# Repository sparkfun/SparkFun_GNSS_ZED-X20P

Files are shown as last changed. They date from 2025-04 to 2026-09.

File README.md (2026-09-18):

SparkFun Allband GNSS RTK Breakout - ZED-X20P (Qwiic)
========================================

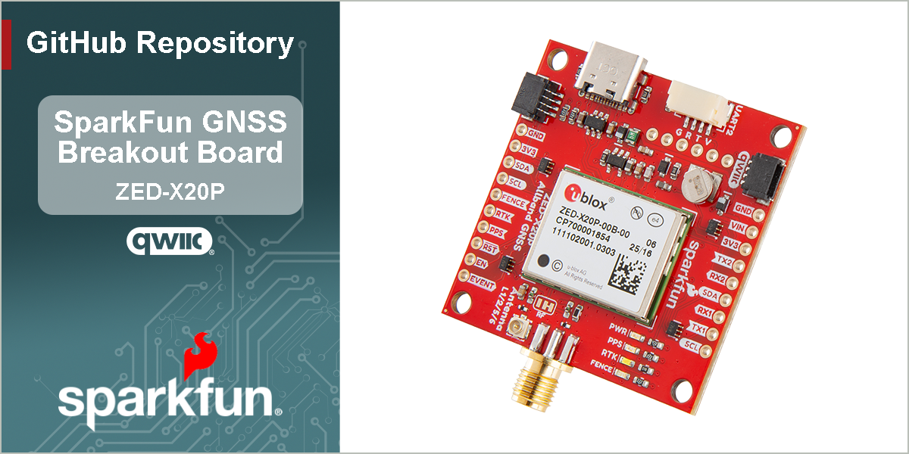
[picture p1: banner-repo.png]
SparkFun Allband GNSS RTK Breakout - ZED-X20P


[*SparkFun Allband GNSS RTK Breakout - ZED-X20P (Qwiic) (GPS-28871)*](https://www.sparkfun.com/sparkfun-allband-gnss-rtk-breakout-zed-x20p-qwiic.html)

The SparkFun All-band GNSS RTK Breakout - ZED-X20P (Qwiic) features the latest GNSS engine from u-blox; the X20, which is a successor to their popular F9 engine. This board's dimensions, pin layout, and connectors are very similar to the [SparkFun GPS-RTK-SMA Breakout - ZED-F9P (Qwiic)](https://www.sparkfun.com/sparkfun-gps-rtk-sma-breakout-zed-f9p-qwiic.html); and in most circumstances, can be used as a drop-in replacement. The board also accommodates users with a diverse choice of interfaces including USB, UART, SPI, and I<sup>2</sup>C.

The ZED-X20P module is an all-band, high precision GNSS receiver that concurrently processes signals from the GPS, Galileo, BeiDou, QZSS, and NavIC constellations across all GNSS frequency bands, including L-band. With positioning algorithms for Real-time Kinematics (RTK), PPP-RTK, and Precise Point Positioning* (PPP) technologies, the module supports standard RTCM corrections for Virtual Reference Stations (VRS) in a Network RTK setup or a local base station setup. Additionally, L-band correction services are natively supported without the need to integrate an external receiver, such as the NEO-D9S.

With its very high update rate, the ZED-X20P module is ideal for control applications, ensuring smooth and reliable operation. The module also protects system integrity with multi-layered defenses, including a Root of Trust, jamming and spoofing detection, cryptographic authentication of navigation messages through Galileo OSNMA, and more. This represents the highest level of integration in a single-chip receiver for the navigation and robotics markets; in unmanned autonomous vehicles (UAVs), guidance systems, and auto-steering applications.

The ZED-X20P module is supported by the u-blox u-center 2 GNSS software for real-time performance analysis, receiver configuration, and data logging. The AssistNow Online, Offline, and Autonomous A-GNSS services can also be used with the module for faster satellite acquisition. Users can also interface with the GNSS module using NMEA 4.11 and UBX binary protocols.

> [!NOTE]
> The USB interface does not fully comply with industry standards and is not suitable for production use. The USB 2.0 FS (full speed, 12 Mbit/s) interface can be used for host communication. Due to the hardware implementation, it may not be possible to certify the USB interface.
>
> `*`: Feature in development

Documentation
-------------

- **[Hookup Guide (mkdocs)](http://docs.sparkfun.com/SparkFun_GNSS_ZED-X20P/)** - A hookup guide for the SparkFun Allband GNSS RTK Breakout - ZED-X20P breakout board hosted by GitHub pages.<br>
   
- [SparkFun u-blox GNSS v3 Arduino Library](https://github.com/sparkfun/SparkFun_u-blox_GNSS_v3) - An Arduino library for the u-blox GNSS modules

Repository Contents
-------------------

- **[/docs](/docs/)** - Online documentation files
  - [/assets](/docs/assets/) - Assets files
    - [/3d_model](/docs/assets/3d_model/) - 3D models for the board
    - [/board_files](/docs/assets/board_files/) - Design files for the board
      - [KiCad Design Files](/docs/assets/board_files/kicad_files.zip) (.zip)
      - [Schematic](/docs/assets/board_files/schematic.pdf) (.pdf)
      - [Dimensions](/docs/assets/board_files/dimensions.pdf) (.pdf)
    - [/component_documentation](/docs/assets/component_documentation/) - Datasheets for hardware components
    - [/img/hookup_guide](/docs/assets/img/hookup_guide/) - Images for hookup guide documentation - Hookup guide images for the board
    - /Hardware - Hardware design files (.brd, .sch)
      - /Production - Production files

Product Variants
----------------

- [GPS-28871](https://www.sparkfun.com/sparkfun-allband-gnss-rtk-breakout-zed-x20p-qwiic.html) - Breakout Board
- Flex Modules
  - [GPS-29362](https://www.sparkfun.com/sparkpnt-gnss-flex-module-zed-x20p.html) - SparkPNT GNSS Flex Module
  - [GPS-28997](https://www.sparkfun.com/sparkpnt-gnss-flex-module-zed-x20p-im19-imu.html) - SparkPNT GNSS Flex Module w/ IMU
- pHAT Kits:
  - [GPS-29887](https://www.sparkfun.com/sparkfun-gnss-flex-phat-zed-x20p.html) - SparkFun GNSS Flex pHAT
  - [GPS-29888](https://www.sparkfun.com/sparkfun-gnss-flex-phat-zed-x20p-im19-imu.html) - SparkFun GNSS Flex pHAT w/ IMU

Version History
---------------

- [v10](https://github.com/sparkfun/SparkFun_GNSS_ZED-X20P/releases/tag/v10) - Initial Release

License Information
-------------------

This product is ***open source***!

Please review the [`LICENSE.md`](./LICENSE.md) file for license information.

If you have any questions or concerns about licensing, please contact technical support on our [SparkFun forums](https://forum.sparkfun.com/viewforum.php?f=152).

Distributed as-is; no warranty is given.

- Your friends at SparkFun.

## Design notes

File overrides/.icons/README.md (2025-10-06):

.icons directory
====================
This folder should contain branding logos for the product documentation

## General Images
- `sfe.svg` - SparkFun flame logo
- `kicad-primary.svg` - Full KiCad logo

## Directory
- `logo` - Other available logos

## SVG Optimizer
- [Remove meta data from svg](https://jakearchibald.github.io/svgomg/)

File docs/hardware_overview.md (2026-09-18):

## :material-folder-cog: Design Files

<!-- Import the component -->
<script type="module" src="https://ajax.googleapis.com/ajax/libs/model-viewer/3.5.0/model-viewer.min.js"></script>

<div class="grid cards desc" markdown>

-   :kicad-primary:{ .enlarge-logo } Design Files

	---

	- :fontawesome-solid-file-pdf: [Schematic](./assets/board_files/schematic.pdf)
	- :material-folder-zip: [KiCad Files](./assets/board_files/kicad_files.zip)
	- :material-rotate-3d: [STEP File](./assets/3d_model/cad_model.step)
	- :fontawesome-solid-file-pdf: [Board Dimensions](./assets/board_files/dimensions.pdf):
		- 1.70" x 1.70" (43.2mm x 43.2mm)

-   <!-- Boxes in tabs -->

	=== "3D Model"
		<article style="text-align: center;" markdown>
		<model-viewer src="../assets/3d_model/web_model.glb" camera-controls poster="../assets/3d_model/poster.png" tone-mapping="neutral" shadow-intensity="2" shadow-softness="0.2" camera-orbit="0deg 75deg 0.103m" field-of-view="25.11deg" style="width: 100%; height: 450px;">
		</model-viewer>

		[Download the `*.step` File](./assets/3d_model/cad_model.step "Click download"){ .md-button .md-button--primary width="250px" }

		</article>

		???+ tip "Manipulate 3D Model"
			<article style="text-align: center;" markdown>

			| Controls       | Mouse                    | Touchscreen    |
			| :------------- | :----------------------: | :------------: |
			| Zoom           | Scroll Wheel             | 2-Finger Pinch |
			| Rotate         | ++"Left-Click"++ & Drag  | 1-Finger Drag  |
			| Move/Translate | ++"Right-Click"++ & Drag | 2-Finger Drag  |

			</article>

	=== "Dimensions"
		<article style="text-align: center;" markdown>
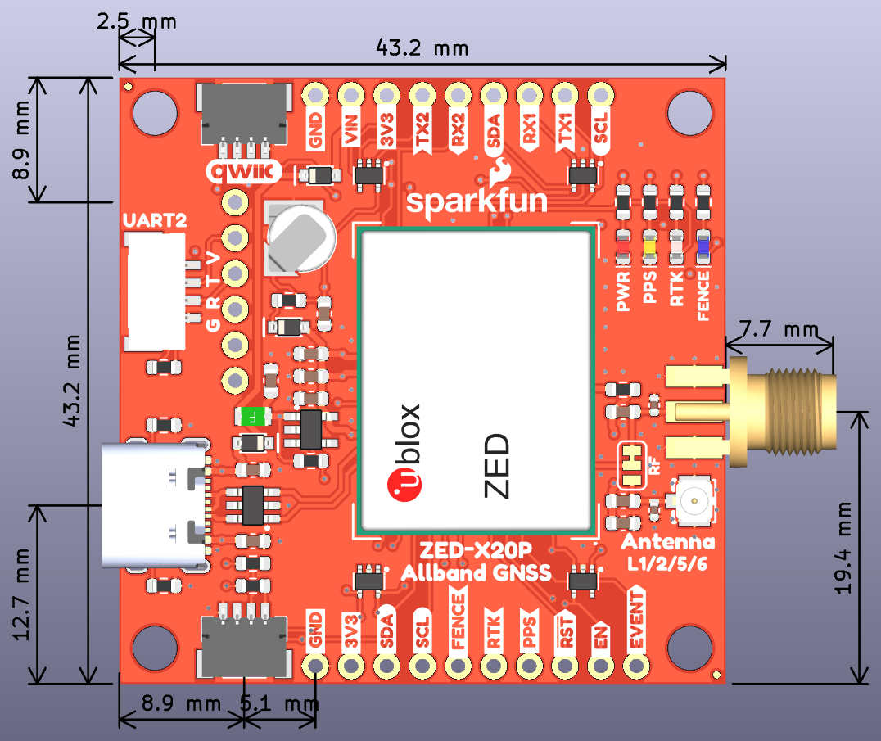
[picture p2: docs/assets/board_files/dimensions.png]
Board Dimensions
		
		<figcaption markdown>Dimensions of the ZED-X20P GNSS breakout board.</figcaption>
		</article>

		???+ tip "Need more measurements?"
			For more information about the board's dimensions, users can download the [KiCad files](./assets/board_files/kicad_files.zip) for this board. These files can be opened in KiCad and additional measurements can be made with the measuring tool.

			!!! info ":octicons-download-16:{ .heart } KiCad - Free Download!"
				KiCad is free, open-source [CAD]("computer-aided design") program for electronics. Click on the button below to download their software. *(\*Users can find out more information about KiCad from their [website](https://www.kicad.org/).)*

				<article style="text-align: center;" markdown>
				[Download :kicad-primary:{ .enlarge-logo }](https://www.kicad.org/download/ "Go to downloads page"){ .md-button .md-button--primary width="250px" }
				</article>

			???+ info ":straight_ruler: Measuring Tool"
				This video demonstrates how to utilize the dimensions tool in KiCad, to include additional measurements:

				<article class="video-500px" style="text-align: center; margin: auto;" markdown>
				<iframe src="https://www.youtube.com/embed/-eXuD8pkCYw" title="KiCad Dimension Tool" frameborder="0" allow="accelerometer; autoplay; clipboard-write; encrypted-media; gyroscope; picture-in-picture" allowfullscreen></iframe>
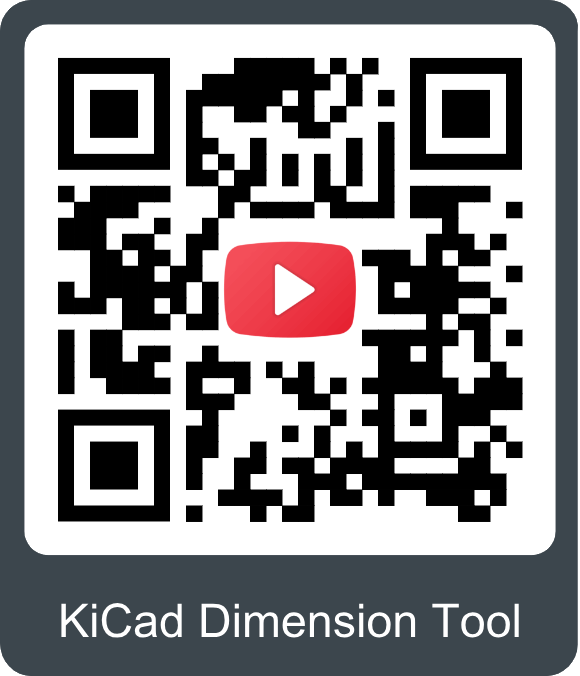
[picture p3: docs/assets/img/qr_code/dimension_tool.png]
QR code to play video
				
				</article>

</div>

## Board Layout
The SparkFun Allband GNSS RTK Breakout - ZED-X20P (Qwiic) features the following:

<div class="grid" markdown>

<div markdown>

<figure markdown>
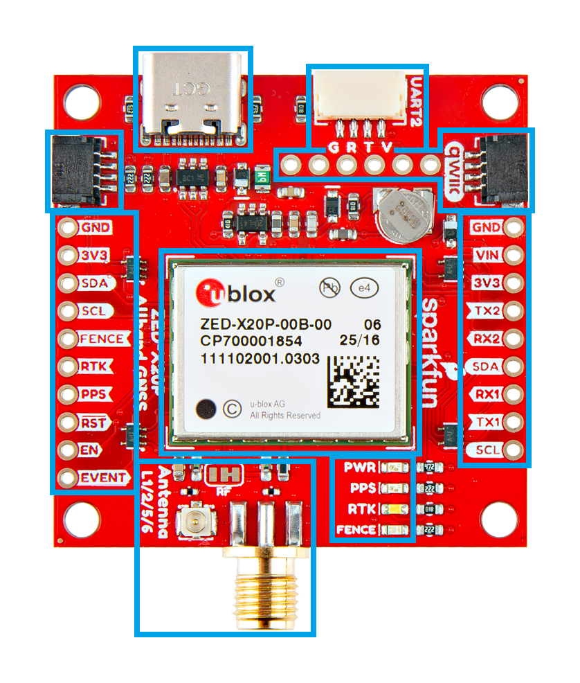
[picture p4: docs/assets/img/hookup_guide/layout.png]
Layout

<figcaption markdown>Layout of the major components on the breakout board.</figcaption>
</figure>

</div>

<div markdown>

1. **USB-C Connector**
:   The primary inteface for powering and interacting with the board
1. **ZED-X20P GNSS Module**
:   The u-blox ZED-X20P GNSS module
1. **Header Pins**
:   Exposes pins to power the board and breaks out the interfaces of the ZED-X20P GNSS module
1. **BlueSMiRF Header Pins**
:   Exposes the `UART2` interface of the ZED-X20P GNSS module
1. **JST Connector**
:   Exposes the `UART2` interface of the ZED-X20P GNSS module
1. **Qwiic Connectors**
:   Exposes the I^2^C interface of the ZED-X20P GNSS module
1. **Status LEDs**
:   LED status indicators for the ZED-X20P GNSS module
1. **`Antenna L1/2/5/6` RF Connectors**
:   SMA and U.FL *(optional)* connectors for an external GNSS antenna

</div>

</div>

## USB-C Connector
A USB connector is provided to power the board and interface with the ZED-X20P GNSS receiver. For most users, it will be the primary method for communicating with the ZED-X20P module.

<figure markdown>
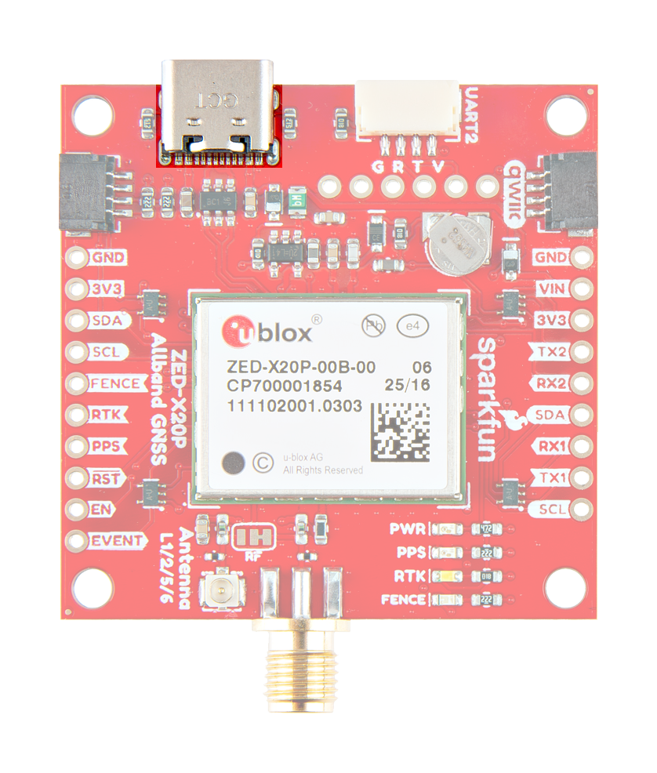
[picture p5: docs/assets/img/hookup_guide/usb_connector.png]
USB-C Connector

<figcaption markdown>USB-C connector on the ZED-X20P GNSS breakout board.</figcaption>
</figure>

## Power
The simplest method to power the board is through the USB-C connector. However, the ZED-X20P GNSS breakout board only requires **3.3V** to power most of its components(1), which can be supplied though JST connector, Qwiic connector, or [PTH](https://en.wikipedia.org/wiki/Through-hole_technology "Plated Through Holes") pins.
{ .annotate }

1. 5V is only required to utilize the USB interface; and when enabled, it can also power the JST connector.

<figure markdown>
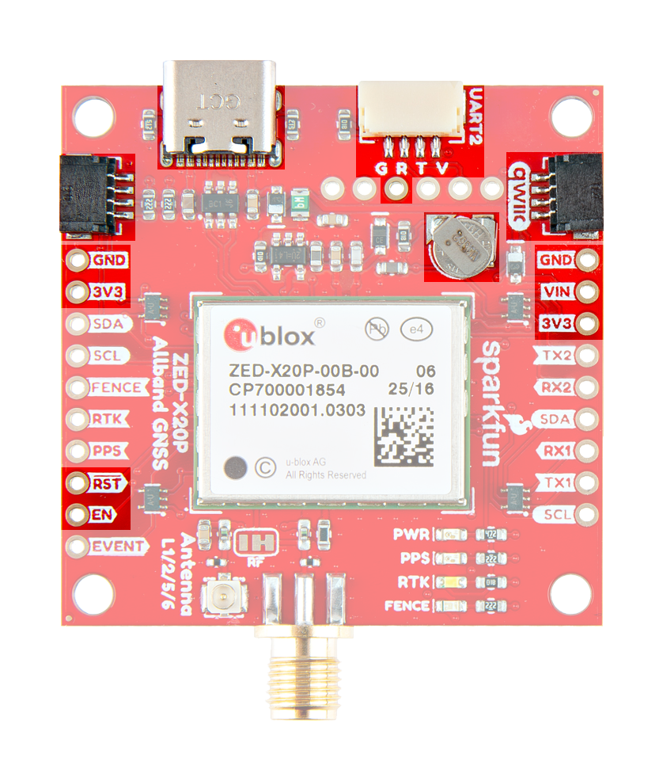
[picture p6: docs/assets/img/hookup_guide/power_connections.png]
Power connections

<figcaption markdown>ZED-X20P GNSS breakout board's power connections.</figcaption>
</figure>

Below, is a general summary of the power circuitry on the board; most are broken out as [PTH](https://en.wikipedia.org/wiki/Through-hole_technology "Plated Through Holes") pins:

<div class="annotate" markdown>

- **`VIN`** - The voltage from the USB-C connector, usually **5V**.
	- Input Voltage Range: 1.2 - 5.5V (1)
	- Power source for the entire board
		- Powers the 3.3V voltage regulator (RT9080), which can source up to 600mA
		- When enabled, it can also power the [BlueSMiRF header](#bluesmirf-header)
- **`3V3`** - Provides a regulated 3.3V from the [RT9080](./assets/component_documentation/RT9080.pdf), using the power supplied from the `VIN` pin or USB-C connector.
	- Used to power the ZED-X20P module, LEDs, [Qwiic connectors](#qwiic), [BlueSMiRF header](#bluesmirf-header), and backup battery
	- Controlled by the `EN` pin, which is enabled by default
- **`EN`** - Enables the voltage output from the [RT9080](./assets/component_documentation/RT9080.pdf), 3.3V voltage regulator
	- Enabled by default *(active `HIGH`)*
- **`RST`** - Used to reset the ZED-X20P GNSS module
	- Connected to the [`RESET_N` pin](#pio-pins) of the ZED-X20P module, an input-only pin with an internal pull-up resistor (2)
	- Driving the pin `LOW` for at least 100ms triggers a cold-start reset, clearing the `BBR` content *(receiver configuration, real-time clock (RTC), and GNSS orbit data)*
- **`GND`** - The common ground or the 0V reference for the voltage supplies.
- **Backup Battery** - Provides backup power to the ZED-X20P GNSS module to maintain ephemeris data for warm starts

</div>

1. While the [RT9080](./assets/component_documentation/RT9080.pdf) LDO regulator has an input voltage range of 1.2 - 5.5V, a minimum supply voltage of **3.5V** is recommended for a 3.3V output.

1. No capacitors should be placed between `RESET_N` to GND, otherwise it could trigger a reset on every startup.

!!! tip "JST Connector"
	The `VSEL` pin of the [BlueSMiRF header](#bluesmirf-header) is designed to operate as a voltage output. However, an input voltage can be supplied through the pin, but users should be mindful of any voltage contention issues.

	Additionally, the jumper for the `VSEL` pin can be modified to change to output voltage level.

!!! info
	For more details, users can reference the [schematic](./assets/board_files/schematic.pdf) and the datasheets of the individual components on the board.

<!-- Not detailed in the datasheet or integration manual, information pulled from another u-blox GNSS module
### Power Modes
The ZED-X20P GNSS module supports three different operation modes:

- **Continuous Mode**

:   In this mode, the module uses dedicated signal processing engines optimized for signal acquisition and tracking.

	- The acquisition engine actively searches and acquires signals, during cold starts or when insufficient signals are available during navigation.
	- The tracking engine continuously tracks signals, downloads all the almanac data, and acquires new signals as they become available during navigation.
	
	The tracking engine consumes less power than the acquisition engine. Therefore, the module's current consumption is lower when a valid position is obtained quickly after startup, the entire almanac has been downloaded, and the ephemeris for available satellites are valid.

- **Backup Modes**

:   The ZED-X20P module supports two backup modes. The backup modes are inactive states with reduced power consumption, where the receiver maintains time, information, and navigation data to speed up signal acquisitions upon restart.

	- **Hardware backup mode**

	:   The hardware backup mode requires `V_BCKP` power to be supplied. It allows the module to enter a backup state and maintain the backup domain (`BBR` and `RTC`), after the main power has been switched off.

	- **Software standby mode**

	:   Software standby mode is entered using the `UBX-RXM-PMREQ` message. This mode will clear the RAM memory; to maintain the receiver configuration, it should be stored on `BBR` or flash layers. The software standby mode can be set for a specific duration, or until the receiver is woken up by a signal from the UART `RX` and/or `EXTINT` pins, as defined in `UBX-RXM-PMREQ` message. A system reset with the `RESET_N` signal also terminates the software standby mode, clears the `BBR` content and restarts the receiver.

- **Safe Boot Mode**
-->

### Power Consumption
The power consumption of the ZED-X20P module depends on the GNSS signals enabled and if the module is acquiring or tacking those signals. The table below, lists the average current consumption with a supply voltage of 3.3V.

<div class="grid cards" markdown>

<article style="text-align: center;" markdown>

| GNSS Signals | Acquisition | Tracking |
| :--- | :---: | :---: |
| GPS+GAL+BDS  | 68mA | 64mA |
| GPS | 55mA | 55mA |

</article>

<div markdown>

!!! tip
	During acquisition, the current consumption may reach up to 85mA; make sure the primary power source can sustain this.

<!--
!!! info "Backup Modes"
	The current consumption for the backup modes:

	- Hardware backup Mode: 31µA
	- Software standby Mode: 49µA
-->

!!! info
	For more information, please refer to the [ZED-X20P Datasheet](./assets/component_documentation/ZED-X20P-00B_DataSheet_UBXDOC-963802114-12690.pdf).

</div>

</div>

## ZED-X20P GNSS Receiver
The centerpiece of this GNSS breakout board is the [ZED-X20P module](./assets/component_documentation/ZED-X20P-00B_DataSheet_UBXDOC-963802114-12690.pdf) from [u-blox](https://www.u-blox.com/en); it features their latest X20 GNSS engine, a successor to their popular F9 engine. The ZED-X20P module is an all-band, high precision GNSS receiver that concurrently processes signals from the GPS, Galileo, BeiDou, QZSS, and NavIC constellations across all GNSS frequency bands, including L-band. With positioning algorithms for Real-time Kinematics (RTK), PPP-RTK, and Precise Point Positioning* (PPP) technologies, the module supports standard RTCM corrections for Virtual Reference Stations (VRS) in a Network RTK setup or a local base station setup. Additionally, L-band correction services are natively supported without the need to integrate an external receiver, such as the NEO-D9S.

With its very high update rate, the ZED-X20P module is ideal for control applications, ensuring smooth and reliable operation. The module also protects system integrity with multi-layered defenses, including a Root of Trust, jamming and spoofing detection, cryptographic authentication of navigation messages through Galileo OSNMA, and more. The module also accommodates users with a diverse choice of interfaces including USB, UART, SPI, and I^2^C.

<div class="grid cards" markdown>

<div markdown>

!!! note
	`*`: Feature in development

<figure markdown>
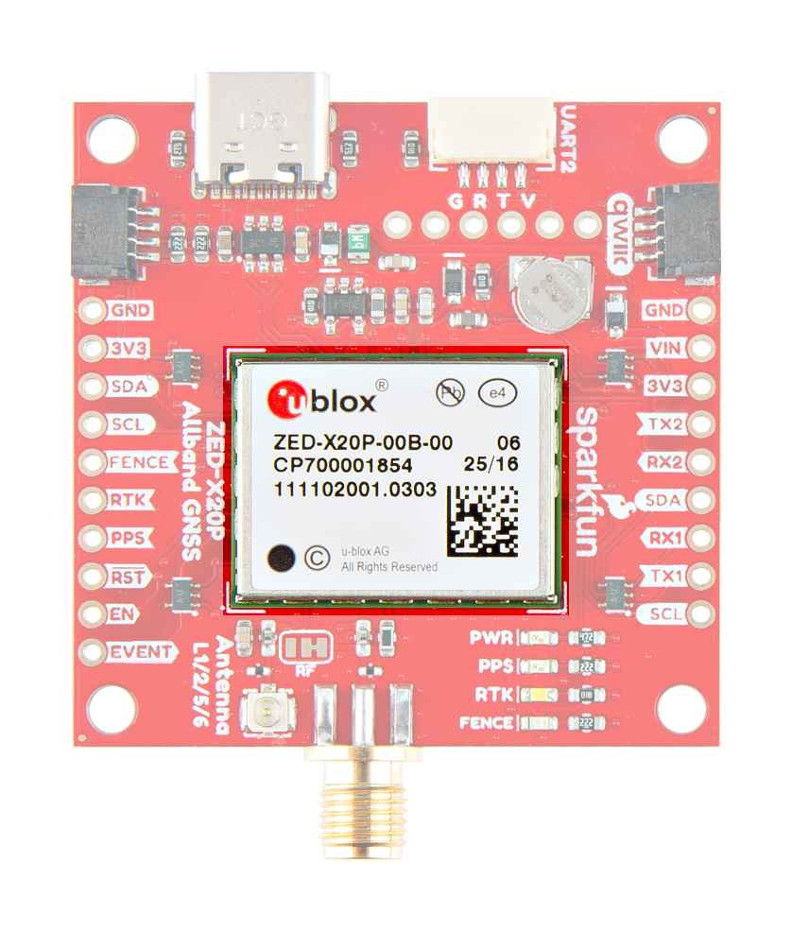
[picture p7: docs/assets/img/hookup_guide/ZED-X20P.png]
ZED-X20P module

<figcaption markdown>The ZED-X20P module on the breakout board.</figcaption>
</figure>

</div>

<div markdown>

<article class="video-500px" style="margin: auto;" markdown>
<iframe src="https://www.youtube.com/embed/dRFR38xS2b4" title="u-blox launches the ZED-X20P. Our first all-band, global GNSS module." frameborder="0" allow="accelerometer; autoplay; clipboard-write; encrypted-media; gyroscope; picture-in-picture" allowfullscreen></iframe>
QR code to play video
</article>

<figure markdown>
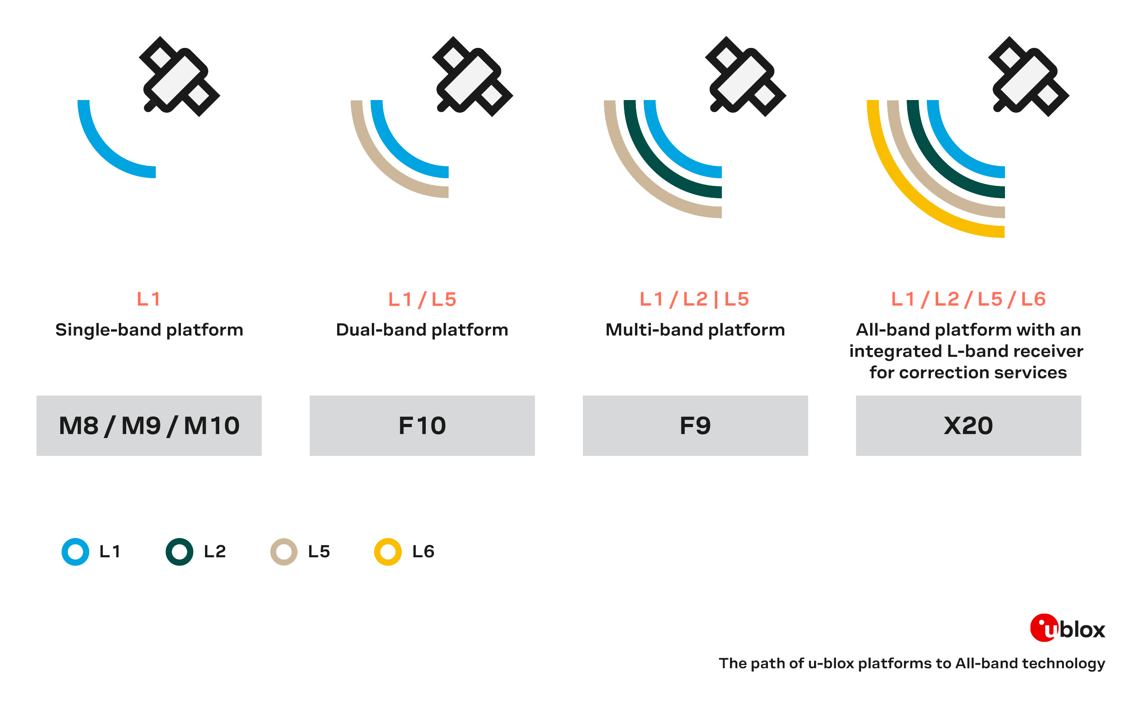
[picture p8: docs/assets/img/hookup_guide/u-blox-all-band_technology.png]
ublox engine (https://content.u-blox.com/sites/default/files/2024-09/X20-u-blox-the-path-of-u-blox-platforms-to-all-band-technologyx20-u-blox-the-path-of-u-blox-platforms-to-all-b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 "Click to enlarge")

<figcaption markdown>The frequency bands supported by the various u-blox GNSS engines.</figcaption>
</figure>

</div>

</div>

<div class="grid" markdown>

<div markdown>

**Features:**

- Supply voltage: 2.7V to 3.6V
- GNSS Constellations:
	- GPS (USA)
	- Galileo (EU)
	- BDS (China)
	- QZSS (Japan)
	- NavIC (India)
- SBAS Systems:
	- WASS (USA)
	- EGNOS (EU)
	- BDSBAS (China)
	- MSAS (Japan)
	- GAGAN (India)
- Sensitivity
	- Tracking and Nav.: -167dBm
	- Reacquisition: -160dBm
	- Cold start: -148dBm
	- Hot start: -158dBm
- Accuracy
	- Dynamic
		- Velocity: 0.03m/s
		- Heading: 0.3&deg;
		- Time Pulse: 60ns
	- Static/Position *(GPS+GAL+BDS)*
		- Horizontal position accuracy (CEP)
			- PVT: 1.2m
			- SBAS: 0.6m
			- RTK: 0.006m + 1ppm
			- PPP-RTK: <0.06m
			- PPP: <0.10m

</div>

<div markdown>

<br>

- Operational limits
	- Dynamics: <4g
	- Altitude: 80,000m
	- Velocity: 300m/s
	- Update Rate: Up to 25Hz
- Time to Fix
	- Cold Start: 25s
	- Aided Start: 2s
	- Hot Start: 2s
- Convergence time:
	- RTK: <7s
	- PPP-RTK: <40s
	- PPP: <120s
- Features
	- Programmable flash memory
	- Carrier phase output
	- Jamming detection
	- Galileo OSNMA
	- Secure boot
- Interfaces:
	- USB
	- UART x2
	- SPI
	- I^2^C
	- Digital I/O
		- `TIMEPULSE` configurable: 0.25 - 10MHz
		- `EXTINT` input for Wakeup
- Protocols: NMEA 4.11, UBX binary, RTCM v. 3.4, SPARTN v. 2.0.2
- Services:
	- AssistNow
	- PointPerfect
- Operating temperature: -40°C to 85°C
- Dimensions: 17.0mm x 22.0mm x 2.4mm

</div>

</div>

### Frequency Bands
The ZED-X20P module is an all-band, high precision GNSS receiver that concurrently processes signals from the GPS, Galileo, BeiDou, QZSS, and NavIC constellations across all GNSS frequency bands, including L-band. Below, are the frequency bands provided by all the global navigation satellite systems and the ones supported by the ZED-X20P module.

<div class="grid" markdown>

<div markdown>

<figure markdown>
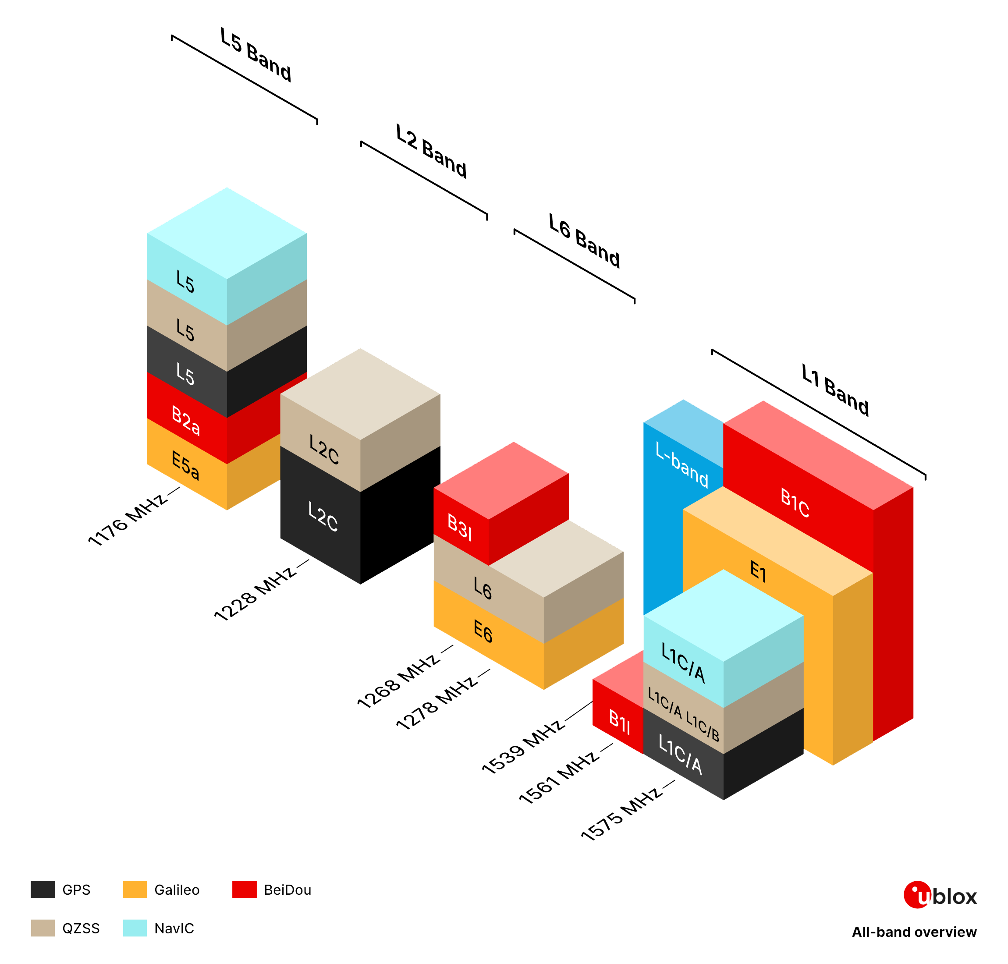
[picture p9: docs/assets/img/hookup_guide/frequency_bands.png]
Supported frequency bands (https://content.u-blox.com/sites/default/files/2025-03/all-band-overview-design.png "Click to enlarge")

<figcaption markdown>The frequency bands supported by the ZED-X20P GNSS receiver.</figcaption>
</figure>

</div>

<div markdown>

<article style="text-align: center;" markdown>

| Constellation | Frequency Bands |
| :---: | :--- |
| GPS | L1C/A, L2C, L5 |
| QZSS | L1C/A, L1C/B*, L2C, L5, L6 |
| GAL | E1B/C, E5a, E6 |
| BDS | B1I, B1C, B2a, B3I |
| NavIC | L1*, L5 |
| SBAS | L1C/A |

*The supported frequency bands, organized by constellation.*
</article>

!!! note
	`*`: Feature in development

</div>

</div>

<figure markdown>
GNSS frequency bands (https://www.tallysman.com/app/uploads/2021/07/Tallysman-GNSS-Frequencies-v8.0_Chart-1-1024x425.png "Click to enlarge")
<figcaption markdown>Frequency bands of the global navigation satellite systems. (Source: [Tallysman](https://www.tallysman.com/gnss-constellations-radio-frequencies-and-signals/))</figcaption>
</figure>

!!! note "Configuration Settings"
	Each GNSS constellations and their signal bands can be enabled or disabled independently, using keys from the `CFG-SIGNAL-*` configuration group; except for the QZSS and SBAS constellation. A GNSS constellation is considered to be enabled when the constellation enable key is set and at least one of the constellation's band keys is enabled. However, the ZED-X20P only supports certain combinations of constellations and bands. For all GNSS constellations, the `L1` band is mandatory even in combination with another frequency band. Any unsupported combinations will be rejected with a `UBX-ACK-NAK` and the warning: `inv sig cfg` will be sent via UBX-INF and NMEA-TXT messages *(if enabled)*.

	??? info "Supported Combinations"

		<article style="text-align: center;" markdown>

		| Constellation key<br>`CFG-SIGNAL-GAL_ENA` | Band key<br>`CFG-SIGNAL-GAL_E1_ENA` | Band key<br>`CFG-SIGNAL-GAL_E5A_ENA` | Band key<br>`CFG-SIGNAL-GAL_E6_ENA` | Constellation enabled? |
		| :---------- | :---------- | :---------- | :---------- | :-: |
		| true (`1`)  | true (`1`)  | true (`1`)  | true (`1`)  | yes |
		| true (`1`)  | true (`1`)  | true (`1`)  | false (`0`) | yes |
		| true (`1`)  | true (`1`)  | false (`0`) | true (`1`)  | yes |
		| true (`1`)  | true (`1`)  | false (`0`) | false (`0`) | yes |
		| true (`1`)  | false (`0`) | true (`1`)  | true (`1`)  | no  |
		| true (`1`)  | false (`0`) | false (`0`) | true (`1`)  | no  |
		| true (`1`)  | false (`0`) | true (`1`)  | false (`0`) | no  |
		| true (`1`)  | false (`0`) | false (`0`) | false (`0`) | no  |
		| false (`0`) | true (`1`)  | true (`1`)  | true (`1`)  | no  |
		| false (`0`) | true (`1`)  | true (`1`)  | false (`0`) | no  |
		| false (`0`) | true (`1`)  | false (`0`) | true (`1`)  | no  |
		| false (`0`) | false (`0`) | true (`1`)  | true (`1`)  | no  |
		| false (`0`) | false (`0`) | false (`0`) | true (`1`)  | no  |
		| false (`0`) | false (`0`) | true (`1`)  | false (`0`) | no  |
		| false (`0`) | true (`1`)  | false (`0`) | false (`0`) | no  |
		| false (`0`) | false (`0`) | false (`0`) | false (`0`) | no  |

		</article>

??? info "What are Frequency Bands?"
	A [frequency band](https://en.wikipedia.org/wiki/Frequency_band) is a section of the [electromagnetic spectrum](https://en.wikipedia.org/wiki/Electromagnetic_spectrum), usually denoted by the range of its upper and lower limits. In the [radio spectrum](https://en.wikipedia.org/wiki/Radio_spectrum), these frequency bands are usually regulated by region, often through a government entity. This regulation prevents the interference of RF communication; and often includes major penalties for any interference with critical infrastructure systems and emergency services.

	<figure markdown>
	GNSS frequency bands (https://gssc.esa.int/navipedia/images/c/cf/GNSS_All_Signals.png "Click to enlarge")
	<figcaption markdown>Frequency bands of the global navigation satellite systems. (Source: [ESA](https://gssc.esa.int/navipedia/index.php?title=File:GNSS_All_Signals.png "European Space Agency"))</figcaption>
	</figure>

	However, if the various GNSS constellations share similar frequency bands, then how do they avoid interfering with one another? Without going too far into detail, the image above illustrates the frequency bands of each system with a few characteristics specific to their signals. Wit these characteristics in mind, along with other factors, the chart can help users to visualize how multiple GNSS constellations might co-exist with each other.

	For more information, users may find these articles of interest:

	- [GNSS signal](https://gssc.esa.int/navipedia/index.php/GNSS_signal)
	- [GPS Signal Plan](https://gssc.esa.int/navipedia/index.php?title=GPS_Signal_Plan)
	- [GLONASS Signal Plan](https://gssc.esa.int/navipedia/index.php?title=GLONASS_Signal_Plan)
	- [GALILEO Signal Plan](https://gssc.esa.int/navipedia/index.php?title=GALILEO_Signal_Plan)

## Peripherals and I/O Pins
The ZED-X20P module has twenty-one I/O pins, of which eight are programmable. Most of these are broken out as [PTH](https://en.wikipedia.org/wiki/Through-hole_technology "Plated Through Holes") pins on the ZED-X20P GNSS breakout board; whereas, others are broken out to their specific interface *(i.e. USB connector, jumper, U.FL connector, etc.)*. Additionally, some of the I/O connections are broken out with multiple components or interfaces.

<div class="grid cards" markdown>

<div markdown>

<figure markdown>
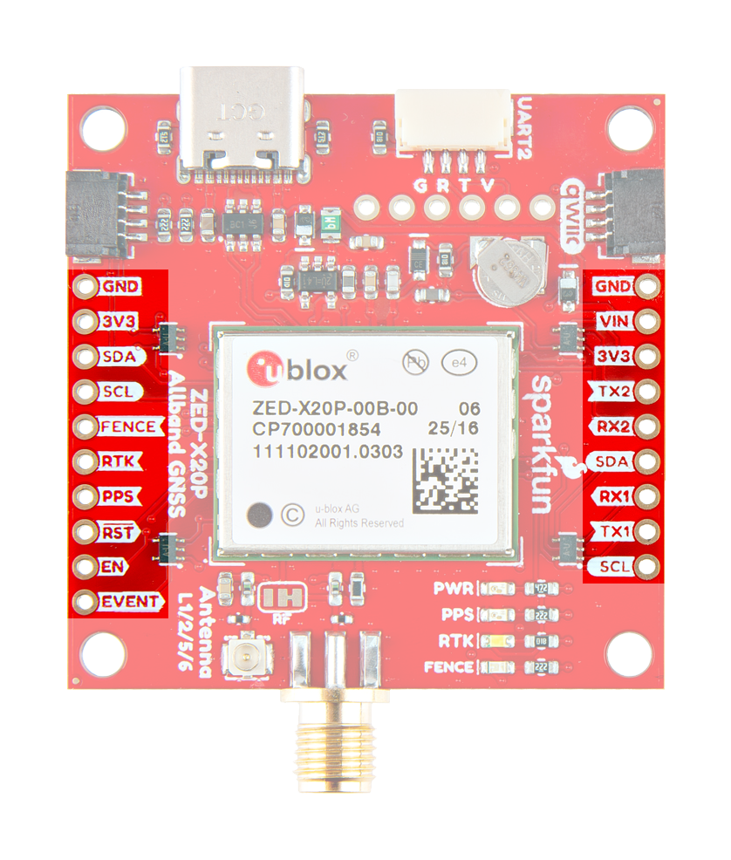
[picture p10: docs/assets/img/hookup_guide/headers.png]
Header pins

<figcaption markdown>The header pins on the ZED-X20P GNSS breakout board.</figcaption>
</figure>

</div>

<div markdown>

<article class="annotate" markdown>
**Interfaces:**

- USB
- UART x2
- SPI
- I^2^C
	- Address *(7-bit)*: **0x42** *(`1000010`)*
- ~~1x Antenna Detect~~ (1)
- ~~1x Antenna Short~~ (2)
- ~~1x Antenna Off~~ (3)
- 1x External interrupt
- 1x PPS output signal
- 1x TX Ready
- 1x RTK Stat
- 1x Geo Stat
- 1x D_Sel pin
- 1x Safe boot pin
- 1x Reset pin

</article>

1. Not available on the ZED-X20P GNSS breakout board.
1. Not available on the ZED-X20P GNSS breakout board.
1. Not available on the ZED-X20P GNSS breakout board.

</div>

</div>

<!--
!!! info "Pin States"
	This table defines the state of the PIO and `RESET_N` pins in different operational modes. The functions of the PIOs are as defined in the default configuration.

	<article style="text-align: center;" markdown>

	| Pin no. | Default function | Continuous mode | Software standby mode | Safe boot mode |
	| :-----: | :--------------- | :-------------: | :-------------------: | :------------: |
	| 47 | `D_SEL`=open<br>`D_SEL`=`GND` | Input pull-up<br>High-Z | Input pull-up<br>Input pull-down | Input pull-up<br>High-Z |
	| 43 | `RXD`<br>`SPI_SDO` | Input pull-up<br>High-Z | Input pull-up | Input pull-up |
	| 42 | `TXD`<br>`SPI_SDI` | Output | Input pull-up | Output |
	| 44 | `SDA`<br>`SPI_CS_N` | Input pull-up / Output<br>High-Z | Input pull-up<br>High-Z | Input pull-up / Output<br>High-Z |
	| 45 | `SCL`<br>`SPI_SLK` | Input pull-up<br>High-Z | Input pull-up<br>High-Z | Input pull-up<br>High-Z |
	| 53 | `TIMEPULSE` | Output | Input pull-up | Output low |
	| 50 | `SAFEBOOT_N` | Input pull-up | Input pull-up | Input pull-up |
	| 51 | `EXTINT` | Input pull-up | Input pull-up | Input pull-up |
	| 26 | `RXD2` | Input pull-up | Input pull-up | Input pull-up |
	| 27 | `TXD2` | Output | Input pull-up | Output |
	| 49 | `RESET_N` | Input pull-up | Input pull-up | Input pull-up |

	</article>

	!!! note
		In reset mode (`RESET_N` = `LOW`), all PIOs are configured as input pull-up.

		In hardware backup mode (VCC = 0V), PIOs must not be driven.
-->

=== "UART Interface"
	The ZED-X20P has two UART interfaces that can be accessed either through the [PTH](https://en.wikipedia.org/wiki/Through-hole_technology "Plated Through Holes") pins. The `UART2` interface can also be accessed through the [BlueSMiRF header](#bluesmirf-header) and the [JST connector](#jst-connector).

	<div class="grid cards desc" markdown>

	<div markdown>

	<figure markdown>
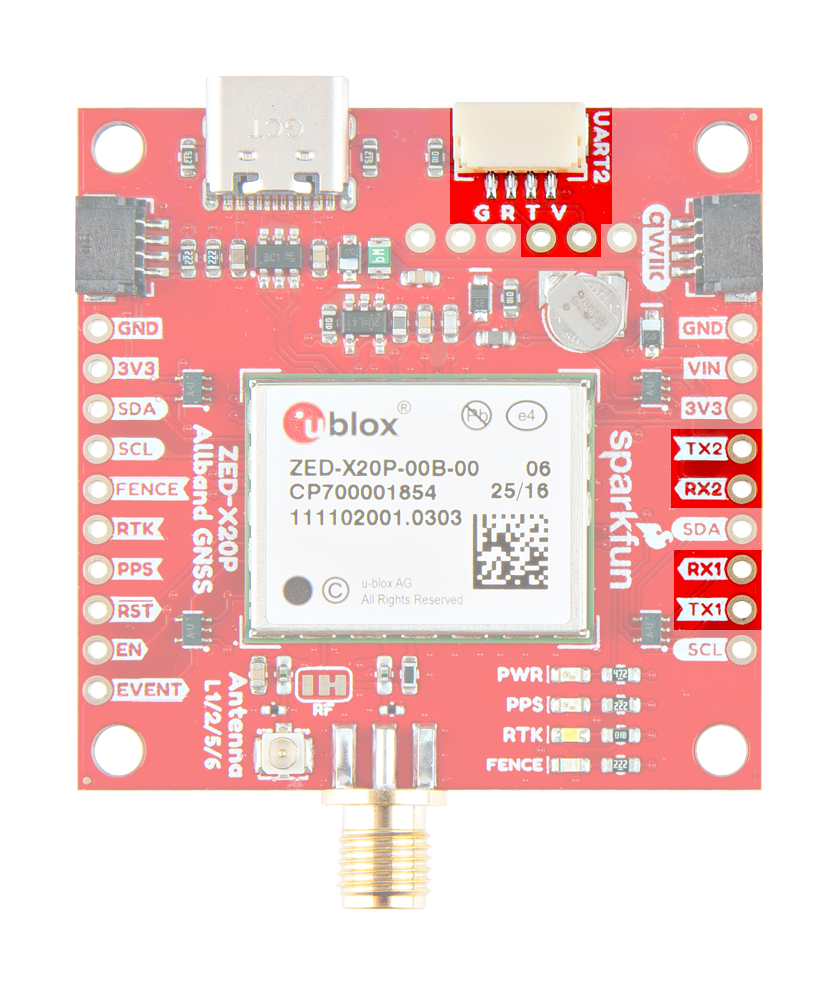
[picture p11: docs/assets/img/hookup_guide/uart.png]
UART connections
	
	<figcaption markdown>The UART interfaces on the ZED-X20P GNSS breakout board.</figcaption>
	</figure>

	!!! tip
		The UART `RX` interface will be disabled when more than 100 frame errors are detected during a one-second period. This can happen if the wrong baud rate is used or the UART `RX` pin is grounded. An error message appears when the UART `RX` interface is reenabled at the end of the one-second period.

	</div>

	<div markdown>

	!!! info "Supported Protocols"
		The UART interface supports the following protocols:

		- Input messages: NMEA (GGA, GLL, GSA, GSV, RMC, VTG, and TXT), RTCM, SPARTN, and UBX
		- Output messages: NMEA, RTCM, and UBX

	!!! info "Configuration Settings"
		The UART interfaces can be configured with the `CFG-UART*` messages, but will initially have the following settings:

		<div class="grid" markdown>

		<div markdown>

		- Baudrate: 4800 to 8000000bps *(Default: 38400bps)*
		- Data Bits: 8
		- Parity: No
		- Stop Bits: 1
		- Flow Control: None

		</div>

		<div markdown>

		- `UART1` Output
			- NMEA protocol with the GGA, GLL, GSA, GSV, RMC, VTG, and TXT output messages are enabled by default.
			- UBX and RTCM 3.4 protocols are enabled by default, but no output messages are enabled by default.
		- `UART1` Input
			- UBX, NMEA, and RTCM 3.4 input protocols are enabled by default.
		- `UART2` Output
			- RTCM 3.4 protocol is enabled by default, but no output messages are enabled by default.
			- NMEA protocol is disabled by default.
		- `UART2` Input
			- RTCM 3.4 and SPARTN protocols are enabled by default.
			- NMEA protocol is disabled by default.

		</div>

		</div>

	</div>

	</div>

	!!! warning "HPG v2.00 Firmware"
		Previously, with firmware HPG v2.00, firmware updates could only be performed with the `UART1` interface.

=== "I^2^C"
	The ZED-X20P has a single I^2^C interface that can be accessed either through the [PTH](https://en.wikipedia.org/wiki/Through-hole_technology "Plated Through Holes") pins or the [Qwiic connector](#qwiic).

	<figure markdown>
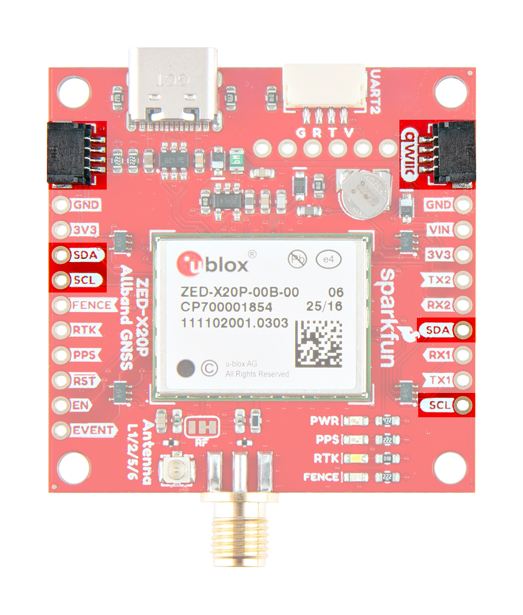
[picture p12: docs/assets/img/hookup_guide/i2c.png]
I2C connections
	
	<figcaption markdown>The I^2^C connections on the ZED-X20P GNSS breakout board.</figcaption>
	</figure>

	!!! info
		For users interested in the specific details about the read and write access for th I^2^C bus, please refer to the [ZED-X20P integration manual](https://www.u-blox.com/sites/default/files/documents/ZED-X20P_IntegrationManual_UBXDOC-963802114-12901.pdf)

	??? tip "What is Qwiic?"

		<div class="grid" markdown>

		<div markdown>

		<!-- Qwiic Banner -->
		<article style="text-align: center;" markdown>
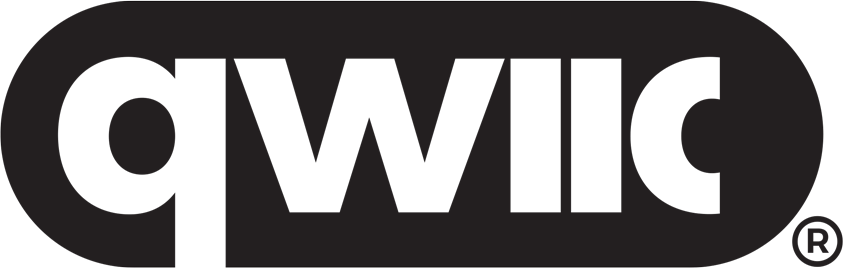
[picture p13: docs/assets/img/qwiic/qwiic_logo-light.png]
Qwiic Logo - light theme (https://www.sparkfun.com/qwiic)
		
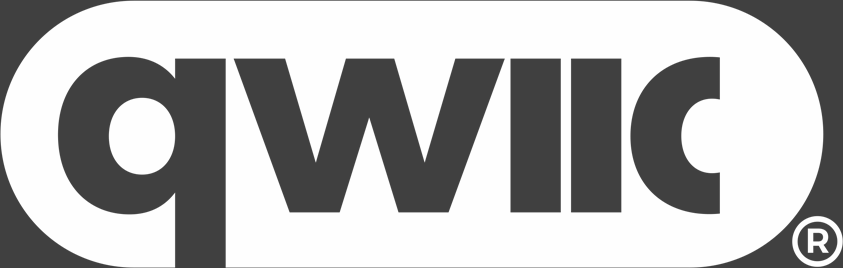
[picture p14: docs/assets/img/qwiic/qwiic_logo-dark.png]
Qwiic Logo - dark theme (https://www.sparkfun.com/qwiic)
		
		</article>

		---

		The [Qwiic connect system](https://www.sparkfun.com/qwiic) is a solderless, polarized connection system that allows users to seamlessly daisy chain I^2^C boards together. Play the video, to learn more about the Qwiic connect system or click on the banner above to learn more about [Qwiic products](https://www.sparkfun.com/qwiic).

		</div>

		<div style="max-height=400px;" markdown>

		<article class="video-500px" style="text-align: center; margin: auto;" markdown>
		<iframe src="https://www.youtube.com/embed/x0RDEHqFIF8" title="SparkFun's Qwiic Connect System" frameborder="0" allow="accelerometer; encrypted-media; gyroscope; picture-in-picture" allowfullscreen></iframe>
		QR code to instructional video
		</article>

		</div>

		</div>

		!!! info "Features of the Qwiic System"

			=== "No Soldering"

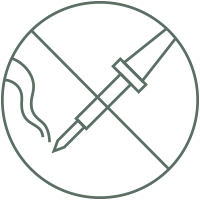
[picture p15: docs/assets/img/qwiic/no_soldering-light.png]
no soldering - light theme
				
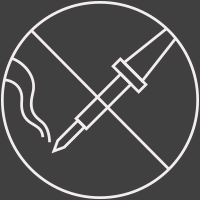
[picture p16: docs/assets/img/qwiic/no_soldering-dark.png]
no soldering - dark theme
				

				Qwiic cables (4-pin JST) plug easily from development boards to sensors, shields, accessory boards and more, making easy work of setting up a new prototype.

			=== "Polarized Connector"

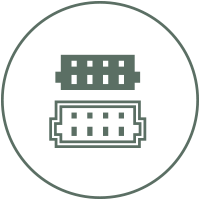
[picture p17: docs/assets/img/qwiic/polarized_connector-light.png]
polarized connector - light theme
				
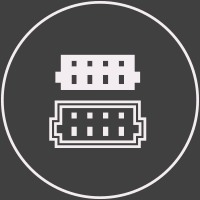
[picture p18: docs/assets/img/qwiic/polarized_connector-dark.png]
polarized connector - dark theme
				

				There's no need to worry about accidentally swapping the SDA and SCL wires on your breadboard. The Qwiic connector is polarized so you know you’ll have it wired correctly every time, right from the start.

				The PCB connector is part number SM04B-SRSS ([Datasheet](https://cdn.sparkfun.com/assets/parts/1/2/2/8/9/Qwiic_Connector_Datasheet.pdf)) or equivalent. The mating connector used on cables is part number SHR04V-S-B or an equivalent *(1mm pitch, 4-pin JST connector)*.

			=== "Daisy Chain-able"

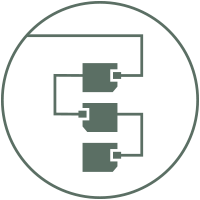
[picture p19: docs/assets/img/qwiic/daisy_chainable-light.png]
daisy chainable - light theme
				
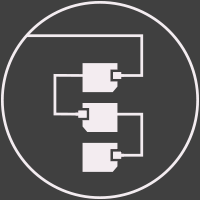
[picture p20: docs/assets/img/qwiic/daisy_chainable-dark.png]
daisy chainable - dark theme
				

				It’s time to leverage the power of the I^2^C bus! Most Qwiic boards will have two or more connectors on them, allowing multiple devices to be connected.

=== "SPI"

	<div class="grid" markdown>

	<div markdown>

	<figure markdown>
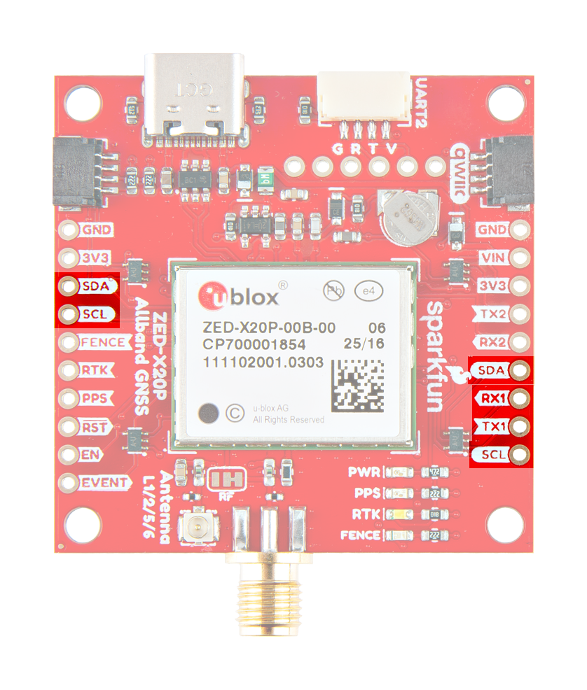
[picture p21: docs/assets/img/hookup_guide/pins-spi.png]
SPI I/O pins
	
	<figcaption markdown>The SPI pins on the ZED-X20P GNSS breakout board.</figcaption>
	</figure>

	</div>

	<div markdown>

	The ZED-X20P has a single SPI interface that can be accessed through the [PTH](https://en.wikipedia.org/wiki/Through-hole_technology "Plated Through Holes") pins. To enable the SPI interface, users must modify the [`SPI` jumper](#jumpers).

	<article style="text-align: center;" markdown>

	| Labels | SPI Pins |
	| :-: | :-: |
	| TX1 | SDO |
	| RX1 | SDI |
	| SDA | CS  |
	| SCL | CLK |

	</article>

	</div>

	</div>

=== "PIO Pins"
	The ZED-X20P module features five programmable I/O pins, but the LNA enable pin is not broken out on this board. All the inputs have internal pull-up resistors in normal operation and can be left open if unused.

	<div class="grid" markdown>

	<div markdown>

	**LED Indicators**

	---

	The `PPS`, `RTK`, and `FENCE` programmable I/O pins are also used as LED indicators.

	<figure markdown>
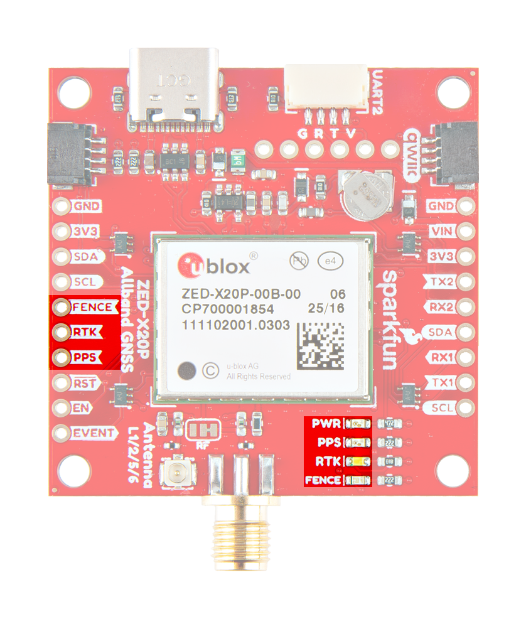
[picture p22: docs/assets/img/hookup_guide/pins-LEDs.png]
LED I/O pins
	
	<figcaption markdown>The signal pins for the LED indicators on the ZED-X20P GNSS breakout board.</figcaption>
	</figure>

	!!! tip "Disable LEDs"
		There are [jumper](#jumpers) attached to the LEDs of the `PPS`, `RTK`, and `FENCE` pins. For low power applications, users can cut the jumper to disable the LED.

	</div>

	<div markdown>

	- **`FENCE`**
	:   The `GEOFENCE_STAT` signal indicates the current geofence status as to whether the receiver is inside any of the active areas. It is possible to configure up to four circular areas as geofence locations. Once configured, the receiver continuously compares its current position with the preset geofenced areas.

			The receiver toggles the assigned pin according to the combined geofence state.

			- **Inside** - The position is inside the geofence with the configured confidence level
			- **Outside** - The position lies outside of the geofence with the configured confidence level
			- **Unknown** - There is no valid position solution or the position uncertainty does not allow for unambiguous state evaluation

			!!! info "Pin State"
				- **`HIGH`** - The `GEOFENCE_STAT` pin is always set to high level when the combined geofence state is unknown
				- **`Low`** - A low level can represent either an inside or outside state based upon the `CFG-GEOFENCE-PINPOL` configuration

	- **`RTK`**
	:   The `RTK_STAT` signal indicates the RTK positioning status and if a stream of valid correction messages is being received.

			!!! info "Pin State"
				- **`LOW`** - Indicates that RTK fixed mode has been achieved
				- *Blinking* - Indicates that a valid stream of correction messages is being received and utilized, but no RTK fixed mode has been achieved
				- **`HIGH`** - Indicates that no carrier phase solution is available

	- **`PPS`**
	:   The [`PPS`](https://en.wikipedia.org/wiki/Pulse-per-second_signal "Pulse Per Second") pin is connected to the module's time pulse (`TIMEPULSE`) signal and the [`PPS` LED](#status-leds), as a visual indicator. The period, length, and polarity (rising or falling edge) of the `TIMEPULSE` signal can be configured with the `CFG-TP-*` messages.

	</div>

	</div>

	<figure markdown>
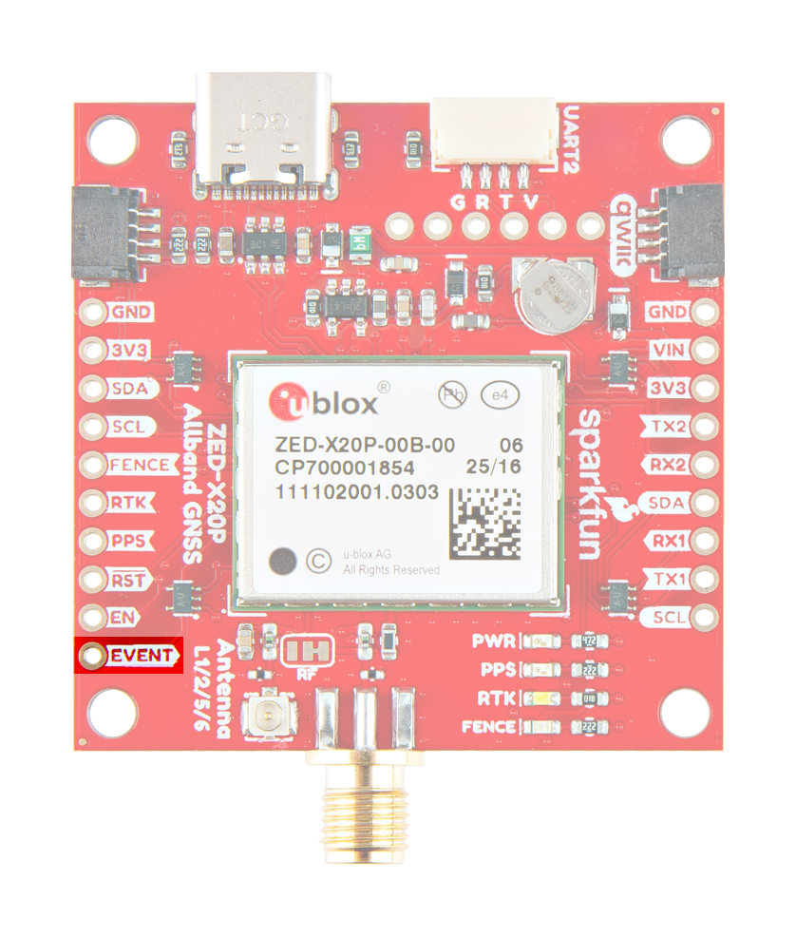
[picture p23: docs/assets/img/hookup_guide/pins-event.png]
Event I/O pin
	
	<figcaption markdown>The `EVENT` pin on the ZED-X20P GNSS breakout board.</figcaption>
	</figure>

	- **`EVENT`**
	:   ZED-X20P supports external interrupts through its `EXTINT` pin. This is useful for waking the module up from its standby mode or for timing applications.

	<figure markdown>
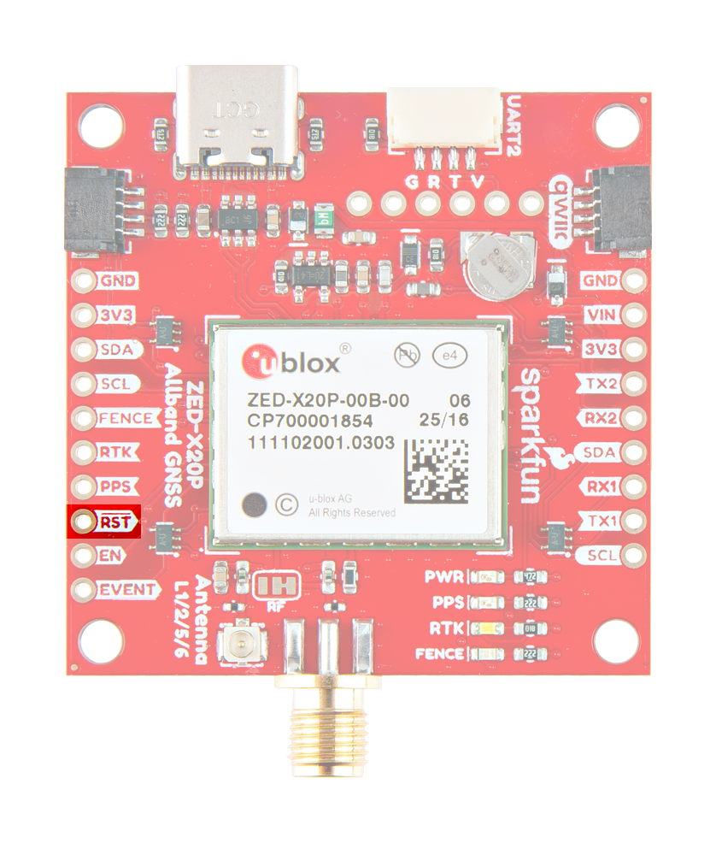
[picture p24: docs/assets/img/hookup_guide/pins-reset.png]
Reset I/O pin
	
	<figcaption markdown>The `RST` pin on the ZED-X20P GNSS breakout board.</figcaption>
	</figure>

	- **`RST`**
	:	The `RST`pin is connected to the `RESET_N` pin of the ZED-X20P module. Driving the pin `LOW` for at least 100ms triggers a cold-start reset, clearing the `BBR` content *(receiver configuration, real-time clock (RTC), and GNSS orbit data)*.

			!!! info
				Capacitors should not be placed between `RST` and `GND`; otherwise, it could trigger a reset on startup.

	- **`D_SEL`**
	:   The `D_SEL` pin can be used to configure the functionality of the combined `UART1`, I^2^C, and SPI interfaces. It is available as the [`SPI` jumper](#jumpers) on the back of the board.

			!!! info
				When pulled `LOW` (by closing the jumper), the `D_SEL` enables the SPI interface on the `UART1` and I^2^C pins.

	!!! note
		The `SAFEBOOT_N` test point is for updates and reconfiguration. The ZED-X20P module will enter safeboot mode, if this pin is pulled `LOW` at startup.

		The `SAFEBOOT_N` and `TIMEPULSE` (`PPS`) pins are internally connected in the ZED-X20P module, by a 1 k&ohm; series resistor. Make sure these pins have no load that could pull them low at startup; otherwise, the receiver will enter its safeboot mode.

### BlueSMiRF Header
The [`UART2` interface](#uart-interface) of the ZED-X20P can be accessed either through the BlueSMiRF header pins or the JST connector. The BlueSMiRF header can be used to connect the ZED-X20P GNSS module to external devices, such as a microcontroller or [BlueSMiRF v2](https://www.sparkfun.com/sparkfun-bluesmirf-v2.html), Bluetooth^&reg;^ serial link.

!!! bug
	In order to protect the ZED-X20P GNSS receiver from high voltage signals, a 1k&ohm; resistor is placed between the `RX` pin of the BlueSMiRF header and the GNS receiver. However, this has impeded the GNSS receiver from receiving data properly.

	This will be remedied on future boards. In the meantime, users can bypass the resistor by utilizing the `RXD2` PTH pin on the edge of the board.

<div class="grid" markdown>

<figure markdown>
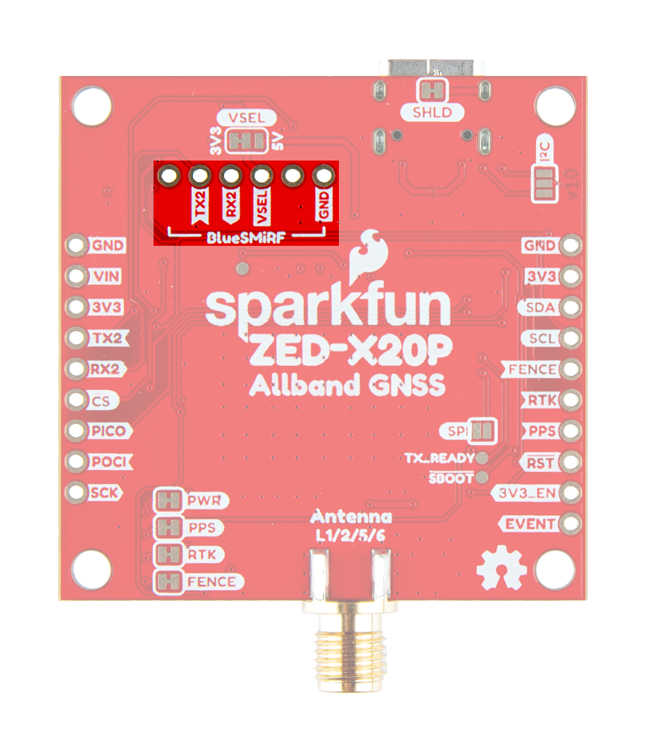
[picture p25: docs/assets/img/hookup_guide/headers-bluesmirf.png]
BlueSMiRF header

<figcaption markdown>The BlueSMiRF header pins on the ZED-X20P GNSS breakout board.</figcaption>
</figure>

<div markdown>

!!! info "Supported Protocols"
	The UART interface supports the following protocols:

	- Input messages: NMEA and UBX
	- Output messages: NMEA (GGA, GLL, GSA, GSV, RMC, VTG, and TXT)

!!! info "Configuration Settings"
	The UART interface can be configured with the `CFG-UART2-*` messages, but will initially have the following settings:

	- Baudrate: 9600 to 8000000bps *(Default: 38400bps)*
	- Data Bits: 8
	- Parity: No
	- Stop Bits: 1
	- Flow Control: None

</div>

</div>

!!! warning "Bus Contention"
	To avoid [bus contention](https://en.wikipedia.org/wiki/Bus_contention) issues between the BlueSMiRF header pins or the JST connector; make sure only one devices is connected to either of these connection options.

!!! tip "Pin Connections"
	When connecting the ZED-X20P GNSS breakout board to another device, users need to be aware of the pin connections and voltage ranges of the products. Below, is a table of the pin connections for the BlueSMiRF header pins on the ZED-X20P GNSS breakout board.

	<article style="text-align: center;" markdown>

	<table border="1" markdown>
	<tr markdown>
	<th style="vertical-align:middle;">Pin Number</th>
	<td align="center" markdown>
		**1**<br>
		*(Left Side)*
	</td>
	<td align="center" markdown>**2**</td>
	<td align="center" markdown>**3**</td>
	<td align="center" markdown>**4**</td>
	<td align="center" markdown>**5**</td>
	<td align="center" markdown>
		**6**<br>
		*(Right)*
	</td>
	</tr>
	<tr markdown>
	<th style="vertical-align:middle;">Label</th>
	<td align="center" markdown>`NC`</td>
	<td align="center" markdown>`TXD`</td>
	<td align="center" markdown>`RXD`</td>
	<td align="center" markdown>`3V3`</td>
	<td align="center" markdown>`NC`</td>
	<td align="center" markdown>`GND`</td>
	</tr>
	<tr markdown>
	<th style="vertical-align:middle;">Function</th>
	<td align="center" markdown></td>
	<td align="center" markdown>UART - Transmit</td>
	<td align="center" markdown>UART - Receive</td>
	<td align="center" markdown>Output Voltage: **3.3V**</td>
	<td align="center" markdown></td>
	<td align="center" markdown>Ground</td>
	</tr>
	</table>

	</article>

### JST Connector
The [`UART2` interface](#uart-interface) of the ZED-X20P can be accessed either through the BlueSMiRF header pins or the JST connector. The JST connector can be used to connect the ZED-X20P GNSS module to external devices, such as the [SiK Telemetry Radio V3](https://www.sparkfun.com/sik-telemetry-radio-v3-915mhz-100mw.html) for RTK corrections.

<div class="grid" markdown>

<figure markdown>
JST Connector
<figcaption markdown>The JST connector on the ZED-X20P GNSS breakout board.</figcaption>
</figure>

<div markdown>

!!! info "Supported Protocols"
	The UART interface supports the following protocols:

	- Input messages: NMEA and UBX
	- Output messages: NMEA (GGA, GLL, GSA, GSV, RMC, VTG, and TXT)

!!! info "Configuration Settings"
	The UART interface can be configured with the `CFG-UART2-*` messages, but will initially have the following settings:

	- Baudrate: 9600 to 8000000bps *(Default: 38400bps)*
	- Data Bits: 8
	- Parity: No
	- Stop Bits: 1
	- Flow Control: None

</div>

</div>

!!! warning "Bus Contention"
	To avoid [bus contention](https://en.wikipedia.org/wiki/Bus_contention) issues between the BlueSMiRF header pins or the JST connector; make sure only one devices is connected to either of these connection options.

!!! tip "Pin Connections"
	When connecting the ZED-X20P GNSS breakout board to another device, users need to be aware of the pin connections and voltage ranges of the products. Below, is a table of the pin connections for the JST connector on the ZED-X20P GNSS breakout board.

	<article style="text-align: center;" markdown>

	<table border="1" markdown>
	<tr markdown>
	<th style="vertical-align:middle;">Pin Number</th>
	<td align="center" markdown>
		**1**<br>
		*(Left Side)*
	</td>
	<td align="center" markdown>**2**</td>
	<td align="center" markdown>**3**</td>
	<td align="center" markdown>
		**4**<br>
		*(Right)*
	</td>
	</tr>
	<tr markdown>
	<th style="vertical-align:middle;">Label</th>
	<td align="center" markdown>`3V3`</td>
	<td align="center" markdown>`TXD`</td>
	<td align="center" markdown>`RXD`</td>
	<td align="center" markdown>`GND`</td>
	</tr>
	<tr markdown>
	<th style="vertical-align:middle;">Function</th>
	<td align="center" markdown>Output Voltage: **3.3V**</td>
	<td align="center" markdown>UART - Transmit</td>
	<td align="center" markdown>UART - Receive</td>
	<td align="center" markdown>Ground</td>
	</tr>
	</table>

	</article>

## External Antenna
The ZED-X20P GNSS breakout board has two options for connecting an external GNSS antenna; the U.FL and SMA connectors. By default, the SMA connector is the primary interface. In order to utilize the U.FL connector, the `RF` jumper must be modified to redirect the signal path from the SMA connector. Then, an external antenna can be connected to the U.FL connector on the board with an U.FL to SMA adapter cable.

<div class="grid" markdown>

<div markdown>

<figure markdown>
GNSS antenna inputs
<figcaption markdown>The RF connections to attach an external GNSS antenna to the ZED-X20P GNSS breakout board.</figcaption>
</figure>

</div>

<div markdown>

<figure markdown>
RF jumper
<figcaption markdown>The `RF` jumper that needs to be modified to utilize the U.FL connector.</figcaption>
</figure>

</div>

</div>

!!! tip
	For the best performance, we recommend users choose a compatible L1/L5 GNSS antenna and utilize a low-loss cable. Also, don't forget that GNSS signals are fairly weak and can't penetrate buildings or dense vegetation. The GNSS antenna should have an unobstructed view of the sky.

## Status LEDs

<div class="grid" markdown>

<figure markdown>
Status LEDs
<figcaption markdown>The status indicator LEDs on the ZED-X20P GNSS breakout board.</figcaption>
</figure>

<div markdown>

There are two status LEDs on the ZED-X20P GNSS breakout board:

- `PWR` - Power *(Red)*
	- Turns on once 3.3V power is supplied to the board
- `PPS` - Pulse-Per-Second *(Yellow)*
	- Indicates when there is a time pulse signal *(see the **[PPS Output](#pps-output)** section)*
- `RTK` - RTK correction indicator *(White)*

	??? info "LED Status"
		- **On** - Indicates that no carrier phase solution is available
		- *Blinking* - Indicates that a valid stream of correction messages is being received and utilized, but no RTK fixed mode has been achieved
		- **Off** - Indicates that RTK fixed mode has been achieved

- `FENCE` - Geofence status indicator *(Blue)*

	??? info "LED Status"
		- **On** - The `GEOFENCE_STAT` pin is always set to high level when the combined geofence state is unknown
		- **Off** - A low level can represent either an inside or outside state based upon the `CFG-GEOFENCE-PINPOL` configuration

!!! info
	For low power applications, the LEDs can be disabled to conserve energy. *See the [**Jumpers** section](#jumpers).*

</div>

</div>

## Jumpers

??? note "Never modified a jumper before?"
	Check out our <a href="https://learn.sparkfun.com/tutorials/664">Jumper Pads and PCB Traces tutorial</a> for a quick introduction!

	<div class="grid cards" markdown align="center">

	-   <a href="https://learn.sparkfun.com/tutorials/664">
		<figure markdown>
		Tutorial thumbnail
		</figure>

		---

		**How to Work with Jumper Pads and PCB Traces**</a>

	</div>

There are eight jumpers on the back of the board that can be used to easily modify the hardware connections on the board.

<figure markdown>
Jumpers
<figcaption markdown>The jumpers on the bottom of the ZED-X20P GNSS breakout board.</figcaption>
</figure>

LED Jumpers
:   Four of the jumpers control power to the status LEDs on the board.

	!!! info
		By default, all the jumpers are connected, to power the status LEDs. For low power applications, users can cut the jumpers to disconnect power from each of the LEDs.

	- **`PWR`** - This jumper can be cut to remove power from the red, power LED.
	- **`PPS`** - This jumper can be cut to remove power from the yellow, `PPS` LED that is provided by the [`PPS` signal](#pps-output).
	- **`RTK`** - This jumper can be cut to remove power from the white, RTK correction LED.
	- **`FENCE`** - This jumper can be cut to remove power from the blue, Geofence status LED.

**<code>I^2^C</code>**
:   This jumper can be be modified to connect pull-up resistors to the `SCL` and `SDA` connections of the I^2^C interface.

**`SPI`**
:   This jumper is connected to the `D_SEL` pin and can be modified to enable the SPI interface on the `RX`, `TX`, `SDA`, and `SCL` pins.

**`VSEL`**
:   This jumper can be modified to configure/disconnect the `VCC` pin of the 4-pin locking JST connector to/from `3V3` or `5V` power.

**`SHLD`**
:   This jumper can be cut to disconnect the shield of the USB-C connector from the board's ground plane.

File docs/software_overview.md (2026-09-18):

## u-center 2 Software
[u-center 2](https://www.u-blox.com/en/product/u-center) is u-blox's software application for configuration, evaluation, and debugging of u-blox GNSS receivers and services. The software provides a relatively, simple graphics user interface to assess and test u-blox GNSS modules for navigation and positioning performance. It also allows users to define or apply GNSS product configurations for specific use cases. Saving, restoring, or sharing configurations between different products is easy.

<div class="grid cards" markdown>

<div markdown>

<article class="video-500px" style="text-align: center; margin: auto;" markdown>
<iframe src="https://www.youtube.com/embed/SCdULSkTcDM" title="u-blox u-center 2" frameborder="0" allow="accelerometer; autoplay; clipboard-write; encrypted-media; gyroscope; picture-in-picture" allowfullscreen></iframe>
QR code
</article>

</div>

<div markdown>

- [Tutorials](https://www.u-blox.com/en/u-center2-tutorials)
- [User Manual](https://www.u-blox.com/en/info/u-center-2-user-guide)
	- [Connecting to a Device](https://www.u-blox.com/en/info/u-center-2-user-guide#32-connecting-a-device)
	- [Device Configuration](https://www.u-blox.com/en/info/u-center-2-user-guide#5-device-configuration)
	- [Views](https://www.u-blox.com/en/info/u-center-2-user-guide#8-views)
		- [Basic Data](https://www.u-blox.com/en/info/u-center-2-user-guide#84-data-view)
		- [Map](https://www.u-blox.com/en/info/u-center-2-user-guide#85-map-view)
		- [Satellites](https://www.u-blox.com/en/info/u-center-2-user-guide#87-satellite-signal-view)
		- [Deviation Plot](https://www.u-blox.com/en/info/u-center-2-user-guide#810-deviation-map-view)

</div>

</div>

!!! warning "Firmware Updates"
	As of HPG v2.02, firmware updates can be performed with the `UART1`, I^2^C, and SPI interfaces of the ZED-X20P. Additionally, when in the safe boot, the ZED-X20P requires an the training sequence to be enabled during the firmware update process.

!!! info "Product Compatibility"
	Gen 10 and later u-blox GNSS modules

### Installation
Installation of the [u-center 2 software](https://www.u-blox.com/en/product/u-center) is straight forward; simply, click on the button below to download the software. User should be aware that the first time the software accessed, they will need to either create or login to their existing u-blox account. If necessary, users can follow the video below or [reference the user manual](https://www.u-blox.com/en/info/u-center-2-user-guide#31-installing-u-center-2) for more instructions.

<div class="grid cards" markdown>

<div markdown>

<article class="video-500px" style="text-align: center; margin: auto;"  markdown>
<iframe src="https://www.youtube.com/embed/UY2XTb72SXA" title="How to download, install &amp; run u-center 2 (ver. 22.10.)" frameborder="0" allow="accelerometer; autoplay; clipboard-write; encrypted-media; gyroscope; picture-in-picture" allowfullscreen></iframe>
QR code
</article>

</div>

<div markdown>

<article style="text-align: center;" markdown>
[:octicons-download-16:{ .heart } Download the u-center 2 from u-blox](https://u-center2-updates.u-blox.com/u-center2-installer.exe){ .md-button .md-button--primary target="blank" }
</article>

???+ info "System Requirements"
	**Operating Systems**

	- Windows 10 or 11

!!! note "User Account Required"
	The first time that users access the software, they will need to either create or login to their existing u-blox account. This requires internet access to login through a web browser. Once the account has been verified, users will no longer need to login again; unless they log out from the u-center 2 software.

</div>

</div>

### Video Tutorials
Users should [reference the user manual](https://www.u-blox.com/en/info/u-center-2-user-guide#31-installing-u-center-2) for more information on the u-center 2 software. However, we have also linked their [webinar](https://www.u-blox.com/en/webinars/u-center2) and some videos from their [Youtube playlist](https://www.youtube.com/playlist?list=PLSzSoRUA4EXuo9NTsbTnK84MiKvbVCEKt) on u-blox's u-center 2 software application.

<div class="grid cards" align="center" markdown>

<article class="video-container" style="text-align: center;" markdown>
<iframe src="https://www.youtube.com/embed/ZYttFyZ_7Uo" title="Explore the possibilities of u-blox positioning device configuration with u-center 2" frameborder="0" allow="accelerometer; autoplay; clipboard-write; encrypted-media; gyroscope; picture-in-picture" allowfullscreen></iframe>
QR code
</article>

<article class="video-container" style="text-align: center;" markdown>
<iframe src="https://www.youtube.com/embed/sA5bCcolwag" title="Getting started with u-center 2 (ver. 22.10.)" frameborder="0" allow="accelerometer; autoplay; clipboard-write; encrypted-media; gyroscope; picture-in-picture" allowfullscreen></iframe>
QR code
</article>

<article class="video-container" style="text-align: center;" markdown>
<iframe src="https://www.youtube.com/embed/RonjsBTdW3A" title="Firmware update on u-center 2 (ver. 23.03.)" frameborder="0" allow="accelerometer; autoplay; clipboard-write; encrypted-media; gyroscope; picture-in-picture" allowfullscreen></iframe>
QR code
</article>

<article class="video-container" style="text-align: center;" markdown>
<iframe src="https://www.youtube.com/embed/OzMneApMMbs" title="How to get started with the u-blox EVK-X20P evaluation kit with u-center 2" frameborder="0" allow="accelerometer; autoplay; clipboard-write; encrypted-media; gyroscope; picture-in-picture" allowfullscreen></iframe>
QR code
</article>

</div>

## PyGPSClient
As an alternative to u-center 2, we recommend [PyGPSClient](https://github.com/semuconsulting/PyGPSClient) for users with computers that run on MacOS or Linux.

???+ info "Resources"
	For additional information, users can refer to the following resources for the PyGPSClient software:

	- :material-github: [GitHub Repository](https://github.com/semuconsulting/PyGPSClient)
	- [Installation Instructions](https://github.com/semuconsulting/PyGPSClient?tab=readme-ov-file#installation)
	- [PyPI Project](https://pypi.org/project/pygpsclient/)

### Installation
There are a variety of [installation methods](https://github.com/semuconsulting/PyGPSClient?tab=readme-ov-file#installation) detailed in the GitHub repository's `README.md` file. However, we recommend utilizing the `pip` installation method.

!!! terminal "Installation Commands"
	Depending on how Python is installed on the computer, one of the following commands should allow users to install the software.

	-
		``` bash
		python3 -m pip install pygpsclient
		```
	-
		``` bash
		pip install pygpsclient
		```

	???+ info "System Requirements"
		This installation method requires an internet connection. Additionally, users will also need administrative privileges *(or root access `sudo`)* for the installation.

### Connecting to the ZED-X20P
Before users can connect to the ZED-X20P GNSS Flex module, they will need to specify the settings of the UART port in PyGPSClient. Once configured, users can select the <kbd>:material-usb:</kbd> button and PyGPSClient will automatically attempt to connect to the GNSS module.

- Below, is a list of the default settings for `UART` ports of the ZED-X20P. These settings should be selected in the configuration menu.
- For the `Serial Port`, select the port associated with the attached UART interface.

<div class="grid" markdown>

<div markdown>

<figure markdown>
UART Settings in PyGPSClient
<figcaption markdown>Specify the settings for the UART port in PyGPSClient.</figcaption>
</figure>

</div>

<div markdown>

???+ tip "Default Settings"
	The UART ports of the ZED-X20P GNSS module will have the following default configuration:

	- Baudrate: 38400bps
	- Data Bits: 8
	- Parity: No
	- Stop Bits: 1
	- Flow Control: None

</div>

</div>

## Arduino IDE
!!! tip
	For first-time users, who have never programmed before and are looking to use the Arduino IDE, we recommend beginning with the <a href="https://www.sparkfun.com/sparkfun-inventor-s-kit-for-arduino-uno-v4-1.html">SparkFun Inventor's Kit (SIK)</a>, which is designed to help users get started programming with the Arduino IDE.

Most users may already be familiar with the Arduino IDE and its use. However, for those of you who have never heard the name *Arduino* before, feel free to check out the [Arduino website](https://www.arduino.cc/en/Guide/HomePage). To get started with using the Arduino IDE, check out our tutorials below:

<div class="grid cards" markdown align="center">

-  <a href="https://learn.sparkfun.com/tutorials/50"><figure markdown>
	What is an Arduino?
	</figure>

	---

	**What is an Arduino?**</a>

-  <a href="https://learn.sparkfun.com/tutorials/61"><figure markdown>
	Installing the Arduino IDE
	</figure>

	---

	**Installing the Arduino IDE**</a>

-  <a href="https://learn.sparkfun.com/tutorials/15"><figure markdown>
	Installing an Arduino Library
	</figure>

	---

	**Installing an Arduino Library**</a>

-  <a href="https://learn.sparkfun.com/tutorials/1265"><figure markdown>
	Installing Board Definitions in the Arduino IDE
	</figure>

	---

	**Installing Board Definitions in the Arduino IDE**</a>
</div>

### SparkFun u-blox GNSS v3 Library
The [SparkFun u-blox GNSS v3](https://github.com/sparkfun/SparkFun_u-blox_GNSS_v3) library can be installed from the library manager in the Arduino IDE by searching for:

	SparkFun u-blox GNSS v3

<div class="grid" markdown>

<div markdown>

<figure markdown>
Library listed in the library manager of the Arduino IDE Click to enlarge
<figcaption markdown>SparkFun u-blox GNSS v3 library in the library manager of the Arduino IDE.</figcaption>
</figure>

</div>

<div markdown>

!!! tip "Manually Download the Arduino Library"
	For users who would like to manually download and install the library, the `*.zip` file can be accessed from the [GitHub repository](https://github.com/sparkfun/SparkFun_u-blox_GNSS_v3) or downloaded by clicking the button below.

	<article style="text-align: center;" markdown>
	[:octicons-download-16:{ .heart } Download the Arduino Library](https://github.com/sparkfun/SparkFun_u-blox_GNSS_v3/archive/refs/heads/main.zip){ .md-button .md-button--primary }
	</article>

</div>

</div>

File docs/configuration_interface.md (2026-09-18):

## Configuration Database

All configuration settings are stored in a database by the receiver.

The configuration database in the receiver's RAM holds the current configuration, which is used by the receiver at run-time. It is constructed on startup of the receiver from the configuration layers. The current configuration is called the RAM Layer. Any configuration in any layer is organized as Configuration Items, where each Configuration Item is referenced to by a unique Configuration Key ID and holds a single Configuration Value.

## Configuration Layers
The receiver has several configuration layers, some of the layers are read-only and others are modifiable. The layers are organized in terms of priority. Values in a high-priority layer replace values stored in a low-priority layers. At startup, the receiver reads all configuration layers and stacks up the items to create the current configuration, which is used by the receiver at run-time.

The following configuration layers are available (in order of priority, highest priority first):

1. **RAM**
:   This layer contains items stored in volatile RAM. This is the Current Configuration. The value of any item can be set by the user at run-time (see UBX protocol interface) and it is effective immediately.
1. **BBR**
:   This layer contains items stored in the battery-backed RAM. The contents in this layer are preserved as long as a battery backup supply is provided during off periods. The value of any item can be set by the user at run-time (see UBX protocol interface) and it becomes effective when the receiver is restarted.
1. **Flash**
:   This layer contains items stored permanently in the external flash memory. This layer is only available if there is a usable external flash memory. The value of any item can be set by the user at run-time (see UBX protocol interface) and it becomes effective when the receiver is restarted.
1. **Default**
:   This layer contains all items known to the running receiver software and their hard- coded default values. Data in this layer is not writable.

4.4.1 UBX protocol interface
The following UBX protocol messages are available to access the Configuration Database:
- `UBX-CFG-VALGET` to read configuration items from the database
- `UBX-CFG-VALSET` to set configuration items in the database
- `UBX-CFG-VALDEL` to delete configuration items from the database

4.7 Configuration reset behavior
The RAM layer is always rebuilt from the layers below when the chip's processor comes out from
reset. When using UBX-CFG-RST the processor goes through a reset cycle with these reset types
(resetMode field):
- `0x00` hardware reset (watchdog) immediately
- `0x01` controlled software reset
- `0x04` hardware reset (watchdog) after shutdown
See section Forcing a receiver reset in the integration manual.

### Configuration Items

| Group | Description |
| :---- | :--- |
| `CFG-HW` | Hardware configuration |
| `CFG-I2C` | Configuration of the I2C interface |
| `CFG-I2CINPROT` | Input protocol configuration of the I2C interface |
| `CFG-I2COUTPROT` | Output protocol configuration of the I2C interface |
| `CFG-MSGOUT` | Message output configuration |
| `CFG-NMEA` | NMEA protocol configuration |
| `CFG-RATE` | Navigation and measurement rate configuration |
| `CFG-SPI` | Configuration of the SPI interface |
| `CFG-SPIINPROT` | Input protocol configuration of the SPI interface |
| `CFG-SPIOUTPROT` | Output protocol configuration of the SPI interface |
| `CFG-TP` | Time pulse configuration |
| `CFG-UART1` | Configuration of the UART1 interface |
| `CFG-UART1INPROT`  | Input protocol configuration of the UART1 interface |
| `CFG-UART1OUTPROT` | Output protocol configuration of the UART1 interface |
| `CFG-UART2` | Configuration of the UART2 interface |
| `CFG-UART2INPROT`  | Input protocol configuration of the UART2 interface |
| `CFG-UART2OUTPROT` | Output protocol configuration of the UART2 interface |

**`NMEA-PUBX`** – u-blox proprietary NMEA messages

| Message | Class/ID | Description (Type) |
| :--- | :---: | :--- |
| `NMEA-PUBX-CONFIG` | `0xf1 0x41` | Set protocols and baud rate (Set) |
| `NMEA-PUBX-RATE` | `0xf1 0x40` | Set NMEA message output rate (Set) |

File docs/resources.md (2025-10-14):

## Product Resources

<div class="grid" markdown>

<div markdown>

- :sfe: [Product Page](https://www.sparkfun.com/sparkfun-allband-gnss-rtk-breakout-zed-x20p-qwiic.html)
- :material-folder-cog: Design Files:
	- :fontawesome-solid-file-pdf: [Board Dimensions](./assets/board_files/dimensions.pdf)
	- :fontawesome-solid-file-pdf: [Schematic](./assets/board_files/schematic.pdf)
	- :material-folder-zip: [KiCad Files](./assets/board_files/kicad_files.zip)
	- :material-rotate-3d: [STEP File](./assets/3d_model/cad_model.step)
- [u-center 2 Software](https://www.u-blox.com/en/product/u-center)
	- [u-center 2 User Manual](https://www.u-blox.com/en/info/u-center-2-user-guide)
	- [Tutorials](https://www.u-blox.com/en/u-center2-tutorials)
- [Building a GNSS System](https://www.sparkfun.com/gps)
- [Qwiic Info Page](https://www.sparkfun.com/qwiic)
- :material-github: [Hardware Repo](https://github.com/sparkfun/SparkFun_GNSS_ZED-X20P)

</div>

<div markdown>

- Component Documentation
	- ZED-X20P
		- :fontawesome-solid-file-pdf: [Datasheet](https://www.u-blox.com/sites/default/files/documents/ZED-X20P-00B_DataSheet_UBXDOC-963802114-12690.pdf)
		- :fontawesome-solid-file-pdf: [Product Summary](https://www.u-blox.com/sites/default/files/documents/ZED-X20P_ProductSummary_UBXDOC-304424225-18238.pdf)
		- :fontawesome-solid-file-pdf: [Integration Manual](https://www.u-blox.com/sites/default/files/documents/ZED-X20P_IntegrationManual_UBXDOC-963802114-12901.pdf)
		- :fontawesome-solid-file-pdf: [GPS L5 Configuration](https://www.u-blox.com/sites/default/files/documents/GPS-L5-configuration_AppNote_UBX-21038688.pdf)
		- Firmware *(HPG 2.02)*
			- :octicons-file-binary-16: [Firmware File](https://content.u-blox.com/sites/default/files/2025-07/UBX_20_HPG_202_ZED_F20P.329facb56ce18631d607fe15177834dc.bin)
			- :fontawesome-solid-file-pdf: [Interface Manual](https://content.u-blox.com/sites/default/files/documents/u-blox-X20-HPG-2.02_InterfaceDescription_UBXDOC-304424225-19967.pdf)
			- :fontawesome-solid-file-pdf: [Release Notes](https://content.u-blox.com/sites/default/files/documents/HPG202_RN_UBXDOC-304424225-20040.pdf)
	- :fontawesome-solid-file-pdf: [RT9080 Datasheet](./assets/component_documentation/RT9080.pdf)
	- :fontawesome-solid-file-pdf: [JST Connector Datasheet](./assets/component_documentation/JST-GH_datasheet.pdf)

</div>

</div>

<!--
- :sfe: [Product Page](https://www.sparkfun.com/sparkfun-allband-gnss-rtk-breakout-zed-x20p-qwiic.html)
- :material-folder-cog: Design Files:
	- :fontawesome-solid-file-pdf: [Board Dimensions](./assets/board_files/dimensions.pdf)
	- :fontawesome-solid-file-pdf: [Schematic](./assets/board_files/schematic.pdf)
	- :material-folder-zip: [KiCad Files](./assets/board_files/kicad_files.zip)
	- :material-rotate-3d: [STEP File](./assets/3d_model/cad_model.step)
- [u-center 2 Software](https://www.u-blox.com/en/product/u-center)
	- [u-center 2 User Manual](https://www.u-blox.com/en/info/u-center-2-user-guide)
	- [Tutorials](https://www.u-blox.com/en/u-center2-tutorials)
- Component Documentation
	- :fontawesome-solid-file-pdf: [Datasheet](https://www.u-blox.com/sites/default/files/documents/ZED-X20P-00B_DataSheet_UBXDOC-963802114-12690.pdf)
	- :fontawesome-solid-file-pdf: [Product Summary](https://www.u-blox.com/sites/default/files/documents/ZED-X20P_ProductSummary_UBXDOC-304424225-18238.pdf)
	- :fontawesome-solid-file-pdf: [Integration Manual](https://www.u-blox.com/sites/default/files/documents/ZED-X20P_IntegrationManual_UBXDOC-963802114-12901.pdf)
	- Application Notes
		- :fontawesome-solid-file-pdf: [GPS L5 Configuration](https://www.u-blox.com/sites/default/files/documents/GPS-L5-configuration_AppNote_UBX-21038688.pdf)
	- Firmware *(HPG 2.02)*
		- :octicons-file-binary-16: [Firmware File](https://content.u-blox.com/sites/default/files/2025-07/UBX_20_HPG_202_ZED_F20P.329facb56ce18631d607fe15177834dc.bin)
		- :fontawesome-solid-file-pdf: [Interface Manual](https://content.u-blox.com/sites/default/files/documents/u-blox-X20-HPG-2.02_InterfaceDescription_UBXDOC-304424225-19967.pdf)
		- :fontawesome-solid-file-pdf: [Release Notes](https://content.u-blox.com/sites/default/files/documents/HPG202_RN_UBXDOC-304424225-20040.pdf)
- [Building a GNSS System](https://www.sparkfun.com/gps)
- [Qwiic Info Page](https://www.sparkfun.com/qwiic)
- :material-github: [Hardware Repo](https://github.com/sparkfun/SparkFun_GNSS_ZED-X20P)
-->

### Additional Resources

- :material-account-supervisor: [SparkFun Technical Assistance](https://www.sparkfun.com/technical_assistance)

## 🏭&nbsp;Manufacturer's Resources
u-blox also provides great resources for the ZED-X20P GNSS receiver module:

- [ZED-X20P Product Page](https://www.u-blox.com/en/product/zed-x20p-module)
- :material-youtube: [u-blox YouTube Channel](https://www.youtube.com/@ublox)
	- :material-playlist-play: [Playlist: u-center 2](https://www.youtube.com/playlist?list=PLSzSoRUA4EXuo9NTsbTnK84MiKvbVCEKt)
- :material-head-question: [Support Page](https://portal.u-blox.com/s/)
- :material-folder-information: [Product Documentation](https://www.u-blox.com/en/product-resources?legacy=Current)
	- :material-head-lightbulb: [PNT Technologies](https://www.u-blox.com/en/positioning-and-location)
	- :material-head-lightbulb: [High Precision Positioning](https://www.u-blox.com/en/technologies/high-precision-positioning)
	- [u-center 2 Software](https://www.u-blox.com/en/product/u-center)
		- [u-center 2 User Manual](https://www.u-blox.com/en/info/u-center-2-user-guide)
		- [Tutorials](https://www.u-blox.com/en/u-center2-tutorials)

<article style="text-align: center;" markdown>
QR code to the hookup guide
</article>

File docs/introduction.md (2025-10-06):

<figure markdown>
Hookup Guide - Thumbnail
</figure>

---

# Introduction

<div class="grid cards desc" markdown>

-   <a href="https://www.sparkfun.com/sparkfun-allband-gnss-rtk-breakout-zed-x20p-qwiic.html">
	**Allband GNSS RTK Breakout - ZED-X20P (Qwiic)**<br>
	**SKU:** GPS-28871

	---

	<figure markdown>
	Product Thumbnail
	</figure></a>

	<article style="text-align: center;" markdown>
	QR code to product page[Purchase from SparkFun :fontawesome-solid-cart-plus:{ .heart }](https://www.sparkfun.com/sparkfun-allband-gnss-rtk-breakout-zed-x20p-qwiic.html){ .md-button .md-button--primary }
	</article>

-   The SparkFun All-band GNSS RTK Breakout - ZED-X20P (Qwiic) features the latest GNSS engine from u-blox; the X20, which is a successor to their popular F9 engine. This board's dimensions, pin layout, and connectors are very similar to the [SparkFun GPS-RTK-SMA Breakout - ZED-F9P (Qwiic)](https://www.sparkfun.com/sparkfun-gps-rtk-sma-breakout-zed-f9p-qwiic.html); and in most circumstances, can be used as a drop-in replacement. The board also accommodates users with a diverse choice of interfaces including USB, UART, SPI, and I^2^C.

	The ZED-X20P module is an all-band, high precision GNSS receiver that concurrently processes signals from the GPS, Galileo, BeiDou, QZSS, and NavIC constellations across all GNSS frequency bands, including L-band. With positioning algorithms for Real-time Kinematics (RTK), PPP-RTK, and Precise Point Positioning* (PPP) technologies, the module supports standard RTCM corrections for Virtual Reference Stations (VRS) in a Network RTK setup or a local base station setup. Additionally, L-band correction services are natively supported without the need to integrate an external receiver, such as the NEO-D9S.

	With its very high update rate, the ZED-X20P module is ideal for control applications, ensuring smooth and reliable operation. The module also protects system integrity with multi-layered defenses, including a Root of Trust, jamming and spoofing detection, cryptographic authentication of navigation messages through Galileo OSNMA, and more. This represents the highest level of integration in a single-chip receiver for the navigation and robotics markets; in unmanned autonomous vehicles (UAVs), guidance systems, and auto-steering applications.

	The ZED-X20P module is supported by the u-blox u-center 2 GNSS software for real-time performance analysis, receiver configuration, and data logging. The AssistNow Online, Offline, and Autonomous A-GNSS services can also be used with the module for faster satellite acquisition. Users can also interface with the GNSS module using NMEA 4.11 and UBX binary protocols.

	!!! note
		The USB interface does not fully comply with industry standards and is not suitable for production use. The USB 2.0 FS (full speed, 12 Mbit/s) interface can be used for host communication. Due to the hardware implementation, it may not be possible to certify the USB interface.

		`*`: Feature in development

</div>

??? question "Product Comparison"
	Below is a simple comparison table between our breakout board and Septentrio's development and evaluation kits:

	<div class="grid cards" markdown>

	<div markdown>

	<figure markdown>
	X20P F9P comparison (https://content.u-blox.com/sites/default/files/2025-03/comparison-u-blox-zed-f9p-and-zed-x20p.png "Click to enlarge")
	<figcaption markdown>A comparison chart between the ZED-X20P and ZED-F9P GNSS modules.</figcaption>
	</figure>

	</div>

	<div markdown>

	<figure markdown>
	ublox engines (https://content.u-blox.com/sites/default/files/2024-09/X20-u-blox-the-path-of-u-blox-platforms-to-all-band-technologyx20-u-blox-the-path-of-u-blox-platforms-to-all-b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 "Click to enlarge")
	<figcaption markdown>A comparison of the frequency bands supported by the various u-blox engines.</figcaption>
	</figure>

	</div>

In this guide we'll cover how to setup the ZED-X20P GNSS breakout board. To follow along with this tutorial, at a minimum, users will need the following items:

<div class="annotate" markdown>

- Computer with an operating system (OS) that is compatible with all the software installation requirements
- [USB 3.1 Cable A to C - 3 Foot](https://www.sparkfun.com/usb-3-1-cable-a-to-c-3-foot.html) - Used to interface with the ZED-X20P GNSS Breakout (1)
- [SparkFun Allband GNSS RTK Breakout - ZED-X20P (Qwiic)](https://www.sparkfun.com/sparkfun-allband-gnss-rtk-breakout-zed-x20p-qwiic.html)
- [GNSS Multi-Band L1/L2/L5 Surveying Antenna](https://www.sparkfun.com/gnss-multi-band-l1-l2-l5-surveying-antenna-tnc-spk6618h.html)
	- [SMA Male to TNC Male Cable](https://www.sparkfun.com/reinforced-interface-cable-sma-male-to-tnc-male-10m.html)
	- [Antenna Mount](https://www.sparkfun.com/gnss-magnetic-antenna-mount-5-8-11-tpi.html)

</div>

1. If your computer doesn't have a USB-A slot, then choose an appropriate cable or adapter.

<div class="grid cards" markdown>

-   <a href="https://www.sparkfun.com/usb-3-1-cable-a-to-c-3-foot.html">
	<figure markdown>
	USB 3.1 Cable A to C - 3 Foot
	</figure>

	---

	**USB 3.1 Cable A to C - 3 Foot**<br>
	CAB-14743</a>

-   <a href="https://www.sparkfun.com/sparkfun-allband-gnss-rtk-breakout-zed-x20p-qwiic.html">
	<figure markdown>
	Product Thumbnail
	</figure>

	---

	**Allband GNSS RTK Breakout - ZED-X20P (Qwiic)**<br>
	GPS-28871</a>

-   <a href="https://www.sparkfun.com/gnss-multi-band-l1-l2-l5-surveying-antenna-tnc-spk6618h.html">
	<figure markdown>
	Product Thumbnail
	</figure>

	---

	**GNSS Multi-Band L1/L2/L5 Surveying Antenna - TNC (SPK6618H)**<br>
	GPS-21801</a>

-   <a href="https://www.sparkfun.com/reinforced-interface-cable-sma-male-to-tnc-male-10m.html">
	<figure markdown>
	Product Thumbnail
	</figure>

	---

	**Reinforced Interface Cable - SMA Male to TNC Male (10m)**<br>
	CAB-21740</a>

-   <a href="https://www.sparkfun.com/gnss-magnetic-antenna-mount-5-8-11-tpi.html">
	<figure markdown>
	Product Thumbnail
	</figure>

	---

	**GNSS Magnetic Antenna Mount - 5/8" 11-TPI**<br>
	PRT-21257</a>

</div>

## Section Topics
This guide is divided into three sections:

- The **Quickstart Guide** assumes a working knowledge of GNSS receiver, development boards, and the required software to program and/or configure them for your project's needs. It only covers basic hardware information and assembly instructions users would need to get started with this product.
- The **Hardware** section has two sub-sections that provide:
	- An overview of the board's design, major components, and interfaces. Refer to this page for information on the connectors, breakout pins, and jumpers.
	- Assembly instructions for this product's interfaces.
- The **Software** section has several sub-sections. The ZED-X20P module has numerous capabilities and a multitude of ways to configure and interface with them.
- In the **Resources** and **Support** sections, users can find the design files (KiCad files & schematic), relevant documentation (datasheets, white papers, etc.) and other helpful links on the Resources page. Lastly, the **Troubleshooting Tips** page includes helpful tips and instructions for how to receive technical support from SparkFun.

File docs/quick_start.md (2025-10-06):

---
icon: material/book-open-page-variant
---

<figure markdown>
Quick Start Guide - Thumbnail
</figure>

---

# Quick Start

<!-- Overview -->
--8<-- "./introduction.md:74:147"

<!-- Board Layout -->
--8<-- "hardware_overview.md:75:112"

<!-- Assembly -->
--8<-- "hardware_assembly.md::23"

<!-- u-center 2 -->
--8<-- "software_overview.md::2"
--8<-- "software_overview.md:43:78"

## Getting Started
Users should [reference the user manual](https://www.u-blox.com/en/info/u-center-2-user-guide#31-installing-u-center-2) for more information on the u-center 2 software.

<div class="video-500px" style="text-align: center; margin: auto;" markdown>
<iframe src="https://www.youtube.com/embed/sA5bCcolwag" title="Getting started with u-center 2 (ver. 22.10.)" frameborder="0" allow="accelerometer; autoplay; clipboard-write; encrypted-media; gyroscope; picture-in-picture" allowfullscreen></iframe>
QR code
</div>

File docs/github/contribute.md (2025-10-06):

## Make an Augmentation!
Spot an improvement opportunity? Feel free to contribute to our open-source design and documentation. 

## :material-file-document-multiple:&nbsp;Improve our Documentation
All of this documentation can be modified by you! Please help us make it better.

- These pages are contained in the [`docs` folder](https://github.com/sparkfun/SparkFun_GNSS_ZED-X20P/tree/main/docs) of the [SparkFun GNSS ZED-X20P repository](https://github.com/sparkfun/SparkFun_GNSS_ZED-X20P).

<!-- ### :material-source-pull:&nbsp;Submit a Correction -->
### Submit a Correction

1. With a GitHub account, [fork this repository](https://github.com/sparkfun/SparkFun_GNSS_ZED-X20P/fork).
2. Add your corrections or improvements to the markdown file.
3. File a pull request with your changes, and enjoy making the ~~words~~ ~~worlds~~ world a better place.
	- Once received, the documentation specialist will automatically be notified.
	- We will review your suggested improvements to make sure they are correct and fit within our documentation standards.

## :material-cog:&nbsp;Improve our Hardware Design
All of our designs are open-source! Please help us make it better.

- Our board design files are contained in the `/Hardware` directories of the [SparkFun GNSS ZED-X20P repository](https://github.com/sparkfun/SparkFun_GNSS_ZED-X20P).

<!-- ### :material-source-pull:&nbsp;Submit a Design Enhancement -->
### Submit a Design Enhancement

1. With a GitHub account, [fork this repository](https://github.com/sparkfun/SparkFun_GNSS_ZED-X20P/fork).
2. Add your design augmentation(s)
3. File a pull request with your changes, and enjoy making the ~~words~~ ~~worlds~~ world a better place.
	1. Once received, the engineer in charge of the original design will automatically be notified.
	2. We will review your suggested improvement(s) to verify that they are within our board design standards and meet our product design requirements.
	3. If approved, we will flag these changes for our next board revision. Congrats! 🍻

		!!! info
			Even if your suggestion is accepted, these changes may not be immediately available for purchase. We may have to cycle through our current product inventory first.

## Contributors&nbsp;:clap:
Let's provide some recognition to the contributors for this project!

GitHub Contributors Image
<br>


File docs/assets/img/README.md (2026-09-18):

img directory
====================
This folder should contain the images for the product documentation

General Images
--------------

- `favicon.ico` - SparkFun flame logo (favicon)
- `banner.psd` - Photoshop Template to generate banner images
- `banner-*.png` - Banner image for the product manual, hookup guide, and/or quick start guide

Directory
---------

- `graphical_datasheet` - Files to generate graphical datasheet
- `hookup_guide` - Images for the hookup guide pages
- `qr_code` - QR code images
- `qwiic` - Images for Qwiic Banner

QR Codes
--------

- [QR code generator](https://qrgenerator.org/)
	- Flame Color: #E0311D
	- Frame Color: #3C464D
- [Remove meta data from svg](https://jakearchibald.github.io/svgomg/)

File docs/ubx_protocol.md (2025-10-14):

## UBX Protocol
u-blox receivers support a u-blox-proprietary protocol (UBX) to communicate with a host computer. This protocol has the following key features:

- Compact - uses 8-bit binary data
- Checksum protected - uses a low-overhead checksum algorithm
- Modular - uses a two-stage message identifier (Class and Message ID)

### Message Structure
The structure of a basic UBX frame is shown in the following diagram.

<figure markdown>
UBX message framework
<figcaption markdown>The structure of a basic UBX message.</figcaption>
</figure>

- Every frame starts with a 2-byte preamble consisting of two synchronization characters: `0xb5` and `0x62`.
- A 1-byte message class field follows. A class is a group of messages that are related to each other.
- A 1-byte message ID field defines the message that is to follow.
- A 2-byte length field follows. The length is defined as being that of the payload only. It does not include the preamble, message class, message ID, length, or UBX checksum fields. The number format of the length field is an unsigned little-endian 16-bit integer (a "U2" in UBX data types).
- The payload field contains a variable number (= length) of bytes.
- The two 1-byte `CK_A` and `CK_B` fields hold a 16-bit checksum whose calculation is defined in UBX checksum section. This concludes the frame.

### Acknowledgement
When messages from the class `CFG` are sent to the receiver, the receiver will send an *acknowledge* (`UBX-ACK-ACK`) or a *not acknowledge* (`UBX-ACK-NAK`) message back to the sender, depending on whether or not the message was processed correctly.

## Common UBX Messages

**`UBX-ACK`** - Acknowledgement and negative acknowledgement messages

| Message | Class/ID | Description (Type) |
| :--- | :---: | :--- |
| `UBX-ACK-ACK` | `0x05 0x01` | Message acknowledged (Output) |
| `UBX-ACK-NAK` | `0x05 0x00` | Message not acknowledged (Output) |

**`UBX-CFG`** - Configuration and command messages

| Message | Class/ID | Description (Type) |
| :--- | :---: | :--- |
| `UBX-CFG-CFG` | `0x06 0x09` | Clear, save, and load configurations (Command) |
| `UBX-CFG-OTP` | `0x06 0x41` | Write file `0xA4`: receiver configuration items (Set) |
| `UBX-CFG-RST` | `0x06 0x04` | Reset receiver/Clear backup data structures (Command) |
| `UBX-CFG-VALDEL` | `0x06 0x8c` | - Delete configuration item values (Set)<br>- Delete configuration item values (with transaction) (Set) |
| `UBX-CFG-VALGET` | `0x06 0x8b` | - Get configuration items (Poll request)<br>- Configuration items (Polled) |
| `UBX-CFG-VALSET` | `0x06 0x8a` | - Set configuration item values (Set)<br>- Set configuration item values (with transaction) (Set) |

**`UBX-MON`** - Monitoring messages

| Message | Class/ID | Description (Type) |
| :--- | :---: | :--- |
| `UBX-MON-SYS` | `0x0A 0x39` | Current system performance information for monitoring purposes |
| `UBX-MON-VER` | `0x0a 0x04` | - Poll receiver and software version (Poll request)<br>- Receiver and software version (Polled) |

**`UBX-NAV`** - Navigation solution messages

| Message | Class/ID | Description (Type) |
| :--- | :---: | :--- |
| `UBX-NAV-HPPOSECEF` | `0x01 0x13` | High precision position solution in ECEF (Periodic/polled) |
| `UBX-NAV-HPPOSLLH`  | `0x01 0x14` | High precision geodetic position solution (Periodic/polled) |
| `UBX-NAV-POSECEF` | `0x01 0x01` | Position solution in ECEF (Periodic/polled) |
| `UBX-NAV-POSLLH` | `0x01 0x02` | Geodetic position solution (Periodic/polled) |
| `UBX-NAV-PVT` | `0x01 0x07` | Navigation position velocity time solution (Periodic/polled) |
| `UBX-NAV-STATUS` | `0x01 0x03` | Receiver navigation status (Periodic/polled) |
| `UBX-NAV-SVIN` | `0x01 0x3b` | Survey-in data (Periodic/polled) |

**`UBX-UPD`** - Firmware update messages

| Message | Class/ID | Description (Type) |
| :--- | :---: | :--- |
| `UBX-UPD-SOS` | `0x09 0x14` | - Poll backup restore status (Poll request)<br>- Create backup in flash (Command)<br>- Clear backup in flash (Command)<br>- Backup creation acknowledge (Output)<br>- System restored from backup (Output)|

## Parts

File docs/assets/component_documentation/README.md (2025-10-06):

SparkFun Documentation
=======================

This directory should include any necessary datasheets, example number crunching, etc.

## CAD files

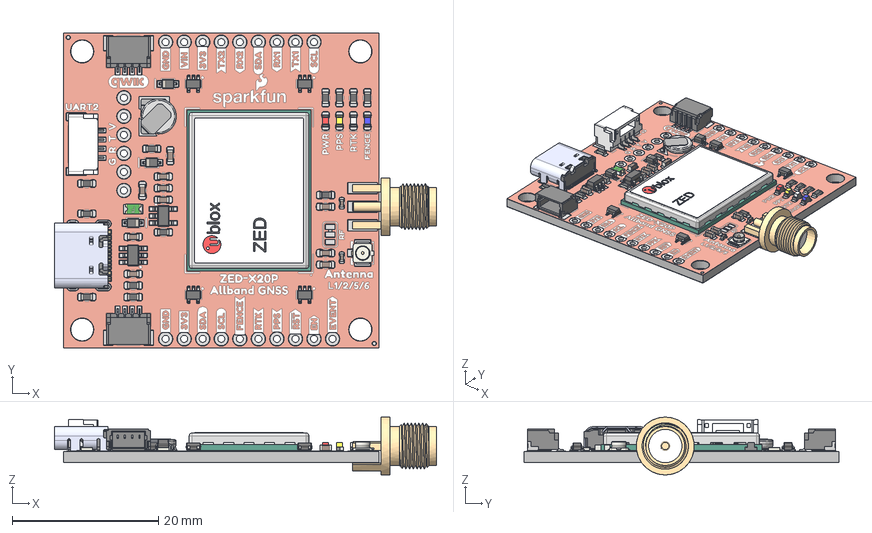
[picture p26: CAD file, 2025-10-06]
docs/assets/3d_model/cad_model.step
52.3 x 43.2 x 7.93 mm
SOT-353_SC-70-5 x 4
LED_0603_1608Metric_Yellow
R_0603_1608Metric x 12
C_0603_1608Metric x 10
USB4105GFA_USB4105GFA
D_SOD-323 x 3
JST_SMD_1.25mm-4_Locking
LED_0603_1608Metric_Red
LED_0603_1608Metric_White
C_0402_1005Metric x 2
Surface 6
Surface 5
Surface 4
Surface 3
Surface 2
Surface 1
Qwiic-Horizontal x 2
SOT-23-5
U.FL
Fuse_0805_2012Metric
SOT-23-6
LED_0603_1608Metric_Blue
isolator
cleme
Anode
Negative
Positive
Imported x 103
Imported_6 x 7
Imported_5
Imported_2
Imported_3
Imported_4
SparkFun_GNSS_ZED-X20P_pad
SparkFun_GNSS_ZED-X20P_silkscreen
SparkFun_GNSS_ZED-X20P_soldermask
SparkFun_GNSS_ZED-X20P_PCB

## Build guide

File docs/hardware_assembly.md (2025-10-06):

## USB Programming
The USB connection is utilized for configuration and communication with the ZED-X20P GNSS module. Users only need to connect their ZED-X20P GNSS breakout board to a computer using a USB-C cable.

<figure markdown>
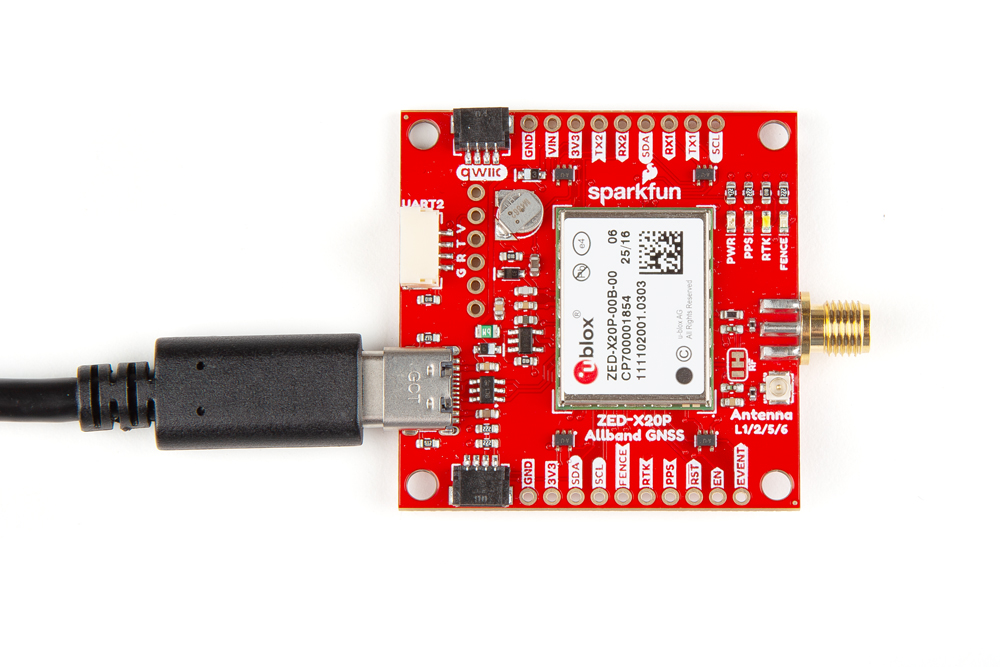
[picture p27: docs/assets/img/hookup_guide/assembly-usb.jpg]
USB connection

<figcaption markdown>The ZED-X20P GNSS breakout board with a USB-C cable attached.</figcaption>
</figure>

## External Antenna
In order to receive [GNSS](https://en.wikipedia.org/wiki/Satellite_navigation "Global Navigation Satellite System") signals, users will need to connect a compatible antenna.

<figure markdown>
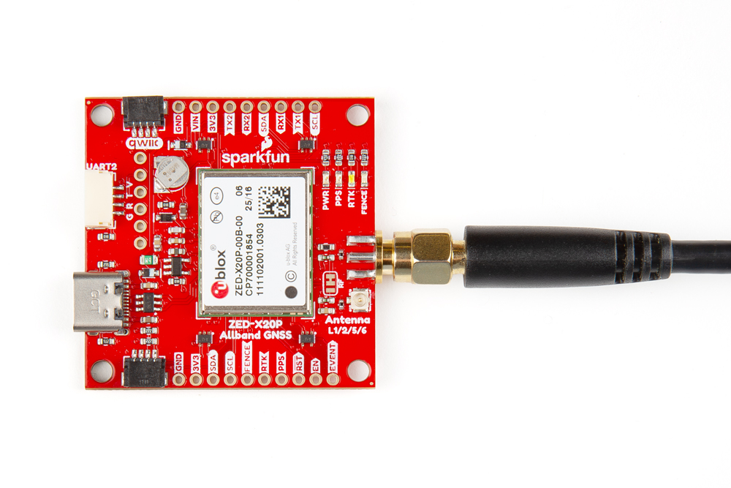
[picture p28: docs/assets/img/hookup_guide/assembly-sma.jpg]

<figcaption markdown>Attaching a GNSS antenna to the SMA connector on the ZED-X20P GNSS breakout board.</figcaption>
</figure>

!!! tip
	For the best performance, we recommend users choose a compatible L1/L2/L5/L-band GNSS antenna and utilize a low-loss cable. Also, don't forget that GNSS signals are fairly weak and can't penetrate buildings or dense vegetation. The GNSS antenna should have an unobstructed view of the sky.

### U.FL Connector
Users have the option of utilizing the U.FL connector to attach an external GNSS antenna. An external antenna can be connected to the U.FL connector on the board with an [U.FL to SMA adapter cable](https://www.sparkfun.com/sma-to-u-fl-cable-150mm.html). In order to utilize the U.FL connector, the `RF` jumper must be modified to change the signal path.

??? note "Never modified a jumper before?"
	Check out our <a href="https://learn.sparkfun.com/tutorials/664">Jumper Pads and PCB Traces tutorial</a> for a quick introduction!

	<article class="grid cards" markdown align="center">

	-   <a href="https://learn.sparkfun.com/tutorials/664">
		<figure markdown>
		Tutorial thumbnail
		</figure>

		---

		**How to Work with Jumper Pads and PCB Traces**</a>

	</article>

<div class="grid" markdown>

<div markdown>

<figure markdown>
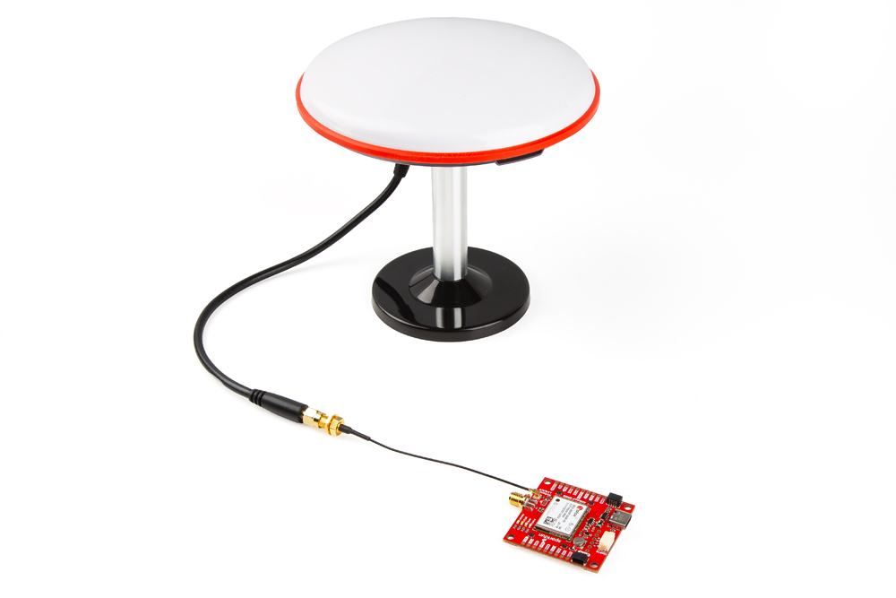
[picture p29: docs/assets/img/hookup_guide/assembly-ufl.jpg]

<figcaption markdown>Connecting an external antenna to U.FL connector on the ZED-X20P GNSS breakout board.</figcaption>
</figure>

</div>

<div markdown>

<figure markdown>
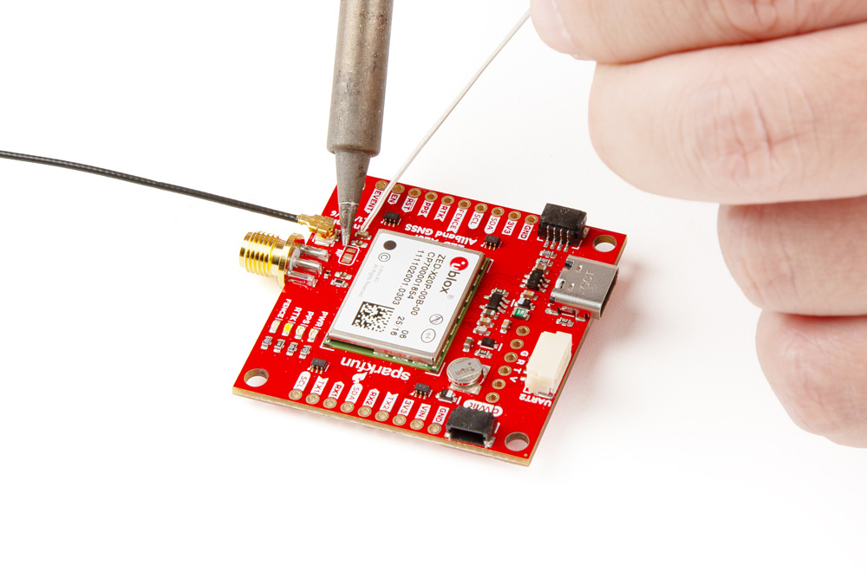
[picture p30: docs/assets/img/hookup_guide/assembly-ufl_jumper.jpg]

<figcaption markdown>Cutting and soldering the `RF` jumper on the ZED-X20P GNSS breakout board, to utilize the GNSS antenna attached to the U.FL connector.</figcaption>
</figure>

</div>

</div>

## Breakout Pins
The [PTH](https://en.wikipedia.org/wiki/Through-hole_technology "Plated Through Holes") pins on the ZED-X20P GNSS breakout board are broken out into 0.1"-spaced pins on the outer edges of the board.

??? note "New to soldering?"
	If you have never soldered before or need a quick refresher, check out our [How to Solder: Through-Hole Soldering](https://learn.sparkfun.com/tutorials/how-to-solder-through-hole-soldering) guide.

	<div class="grid cards" markdown align="center">

	-   <a href="https://learn.sparkfun.com/tutorials/5">
		<figure markdown>
		Tutorial thumbnail
		</figure>

		---

		**How to Solder: Through-Hole Soldering**</a>

	</div>

<div class="grid" markdown>

<div markdown>

**Headers**

---

When selecting headers, be sure you are aware of the functionality you require.

<figure markdown>
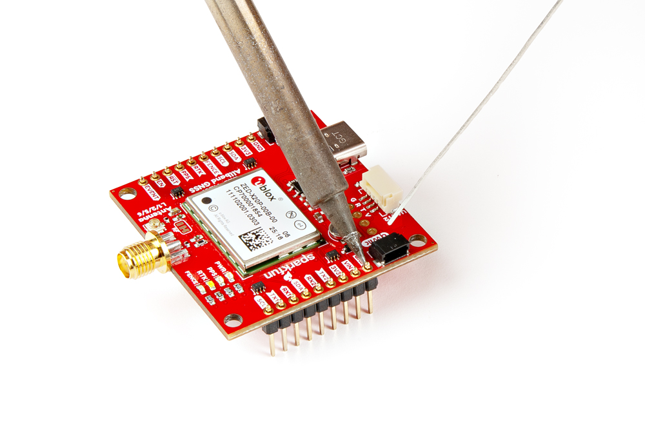
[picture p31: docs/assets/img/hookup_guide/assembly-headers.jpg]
Soldering headers

<figcaption markdown>Soldering headers to the ZED-X20P GNSS breakout board.</figcaption>
</figure>

</div>

<div markdown>

**Hookup Wires**

---

For a more permanent connection, users can solder wires directly to the board.

<figure markdown>
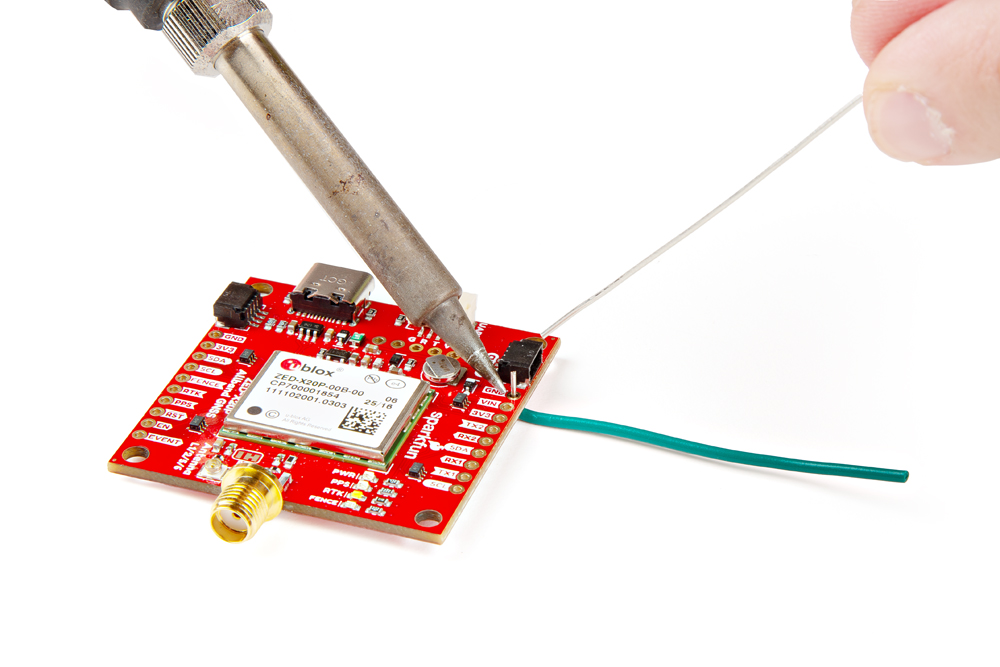
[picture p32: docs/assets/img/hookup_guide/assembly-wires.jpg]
Soldering wires

<figcaption markdown>Soldering wires to the ZED-X20P GNSS breakout board.</figcaption>
</figure>

</div>

</div>

### BlueSMiRF Header Pins
One of the three sets of [PTH](https://en.wikipedia.org/wiki/Through-hole_technology "Plated Through Holes") pins on the ZED-X20P GNSS breakout board is labeled `BlueSMiRF`. This set of header pins breaks out the `UART2` interface of the ZED-X20P module, which can be connected to a microcontroller or RF transceiver; such as the [BlueSMiRF *v2*](https://www.sparkfun.com/sparkfun-bluesmirf-v2-headers.html), Bluetooth^&reg;^ serial link. The BlueSMiRF *v2* comes in two variations, with [PTH pins](https://www.sparkfun.com/sparkfun-bluesmirf-v2.html) or [male header pins](https://www.sparkfun.com/sparkfun-bluesmirf-v2-headers.html). Users can directly solder the PTH variant to the board with [male headers](https://www.sparkfun.com/break-away-headers-straight.html), for a more permanent installation; otherwise, for more flexibility, a [stackable header](https://www.sparkfun.com/arduino-stackable-header-6-pin.html) can be utilized.

<div class="grid" markdown>

<figure markdown>
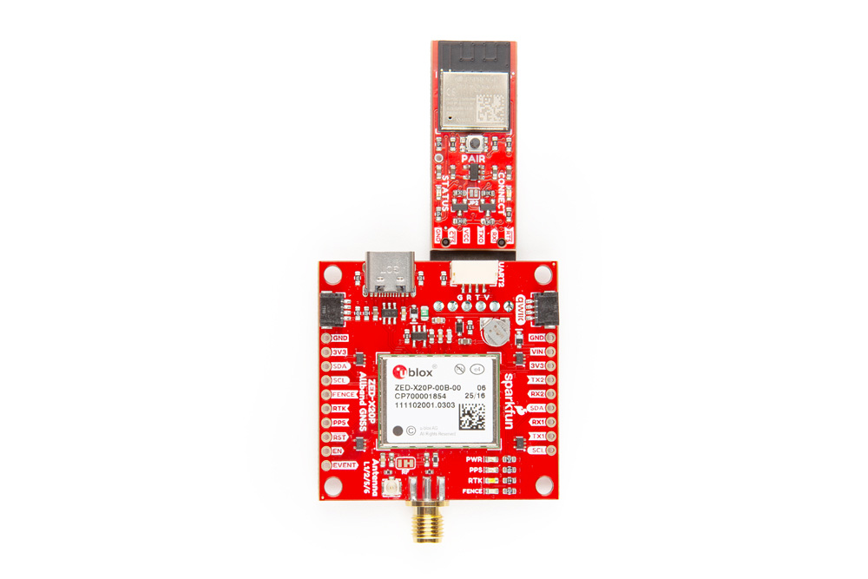
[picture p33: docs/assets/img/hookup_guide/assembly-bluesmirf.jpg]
BlueSMiRF header

<figcaption markdown>Connecting the BlueSMiRF serial link with a [stackable header](https://www.sparkfun.com/arduino-stackable-header-6-pin.html) to the ZED-X20P GNSS breakout board.</figcaption>
</figure>

<figure markdown>
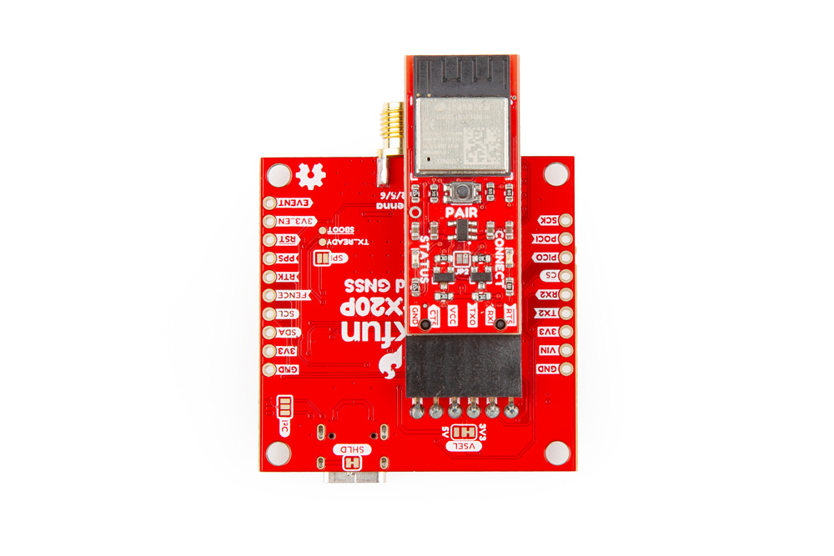
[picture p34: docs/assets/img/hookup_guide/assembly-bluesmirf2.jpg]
BlueSMiRF header

<figcaption markdown>Connecting the BlueSMiRF serial link in a more compact orientation.</figcaption>
</figure>

</div>

!!! info "Default Settings"
	- Baudrate: 38400bps
	- Data Bits: 8
	- Parity: No
	- Stop Bits: 1

When connecting the ZED-X20P GNSS breakout board to another device, users need to be aware of the pin connections and voltage ranges of the products. Below, is a table of the pin connections that users can reference.

<article style="text-align: center;" markdown>

<table border="1" markdown>
<tr markdown>
<th style="vertical-align:middle;">Pin Number</th>
<td align="center" markdown>
	**1**<br>
	*(Left Side)*
</td>
<td align="center" markdown>**2**</td>
<td align="center" markdown>**3**</td>
<td align="center" markdown>**4**</td>
<td align="center" markdown>**5**</td>
<td align="center" markdown>
	**6**<br>
	*(Right)*
</td>
</tr>
<tr markdown>
<th style="vertical-align:middle;">Label</th>
<td align="center" markdown>`NC`</td>
<td align="center" markdown>`TXD`</td>
<td align="center" markdown>`RXD`</td>
<td align="center" markdown>`3V3`</td>
<td align="center" markdown>`NC`</td>
<td align="center" markdown>`GND`</td>
</tr>
<tr markdown>
<th style="vertical-align:middle;">Function</th>
<td align="center" markdown></td>
<td align="center" markdown>UART - Transmit</td>
<td align="center" markdown>UART - Receive</td>
<td align="center" markdown>Output Voltage: **3.3V**</td>
<td align="center" markdown></td>
<td align="center" markdown>Ground</td>
</tr>
</table>

</article>

## JST Connector
The `BlueSMiRF` header pins and JST connector, both break out the `UART2` interface of the ZED-X20P module. The JST connector can be used to attach to the [SiK Telemetry Radio V3](https://www.sparkfun.com/sik-telemetry-radio-v3-915mhz-100mw.html) for RTK corrections.

<div class="grid" markdown>

<figure markdown>
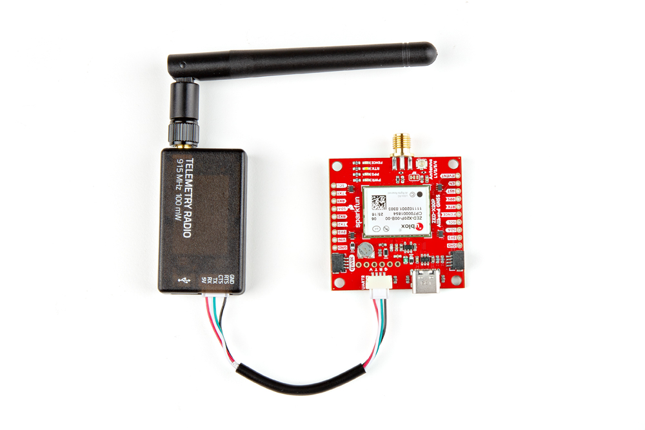
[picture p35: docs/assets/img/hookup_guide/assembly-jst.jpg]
JST connector

<figcaption markdown>Connecting the SiK Telemetry Radio V3 to the ZED-X20P GNSS breakout board.</figcaption>
</figure>

<figure markdown>
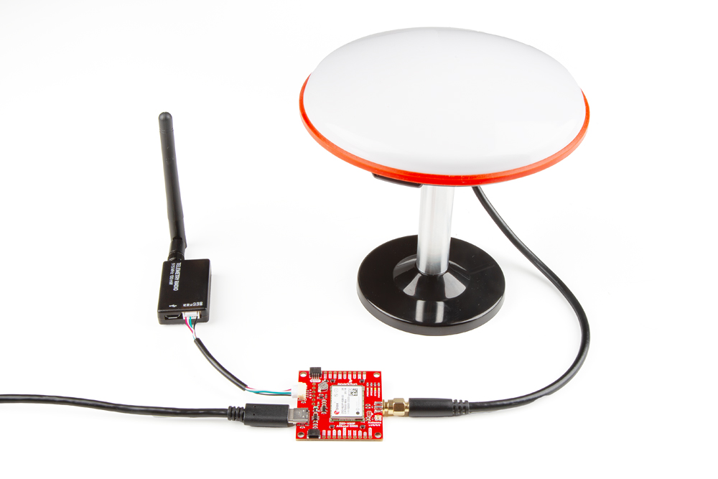
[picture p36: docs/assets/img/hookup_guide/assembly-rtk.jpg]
RTK setup

<figcaption markdown>Operating the ZED-X20P GNSS breakout board as an RTK base station, transmitting RTK corrections with the SiK Telemetry Radio V3.</figcaption>
</figure>

</div>

!!! info "Default Settings"
	- Baudrate: 38400bps
	- Data Bits: 8
	- Parity: No
	- Stop Bits: 1

When connecting the ZED-X20P GNSS breakout board to another device, users need to be aware of the pin connections and voltage ranges of the products. Below, is a table of the pin connections that users can reference.

<article style="text-align: center;" markdown>
<table border="1" markdown>
<tr markdown>
<th style="vertical-align:middle;">Pin Number</th>
<td align="center" markdown>
	**1**<br>
	*(Left Side)*
</td>
<td align="center" markdown>**2**</td>
<td align="center" markdown>**3**</td>
<td align="center" markdown>
	**4**<br>
	*(Right)*
</td>
</tr>
<tr markdown>
<th style="vertical-align:middle;">Label</th>
<td align="center" markdown>`3V3`</td>
<td align="center" markdown>`TXD`</td>
<td align="center" markdown>`RXD`</td>
<td align="center" markdown>`GND`</td>
</tr>
<tr markdown>
<th style="vertical-align:middle;">Function</th>
<td align="center" markdown>Output Voltage: **3.3V**</td>
<td align="center" markdown>UART - Transmit</td>
<td align="center" markdown>UART - Receive</td>
<td align="center" markdown>Ground</td>
</tr>
</table>

</article>

## Qwiic Devices
The Qwiic system allows users to effortlessly prototype with a Qwiic compatible I^2^C device without soldering. Users can attach ZED-X20P GNSS breakout board along with other Qwiic [sensors or boards](https://www.sparkfun.com/special-categories/qwiic.html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) to any [Qwiic compatible microcontroller](https://www.sparkfun.com/development-boards/microcontrollers.html?sf_global_qwiic_connector=8262), with just a few [Qwiic cables](https://www.sparkfun.com/sparkfun-qwiic-cable-kit.html). (*\*The example below, is for demonstration purposes and is not pertinent to the board functionality or this tutorial.*)

<figure markdown>
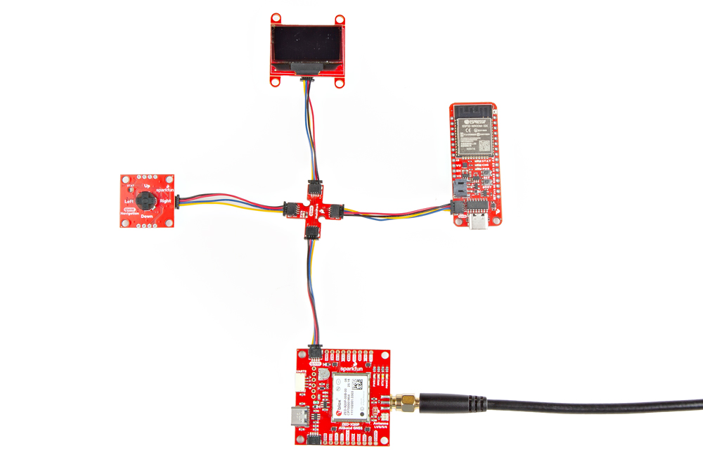
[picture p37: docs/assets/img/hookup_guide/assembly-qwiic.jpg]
Qwiic devices connected

<figcaption markdown>Several Qwiic devices and microcontroller connected to the ZED-X20P GNSS breakout board.</figcaption>
</figure>

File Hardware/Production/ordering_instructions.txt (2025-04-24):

Ordering Instructions:
Panel dimensions: 174.72 x 144.24 mm.
Controlled Impedance: JLC04161H-7628
Material: TG155
Solder Mask: Red
Silkscreen Color: White
Layers: 4
Finish: ENIG
Thickness: 1.6mm
Outer Copper Weight: 1oz
Inner Copper Weight: 0.5oz
Minimum track width: 0.15mm (6.00mil)
Minimum via drill: 0.30mm (11.81mil)
No Clean Process

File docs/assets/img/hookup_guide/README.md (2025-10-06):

hookup_guide directory
====================
This folder should contain images for the hookup guide

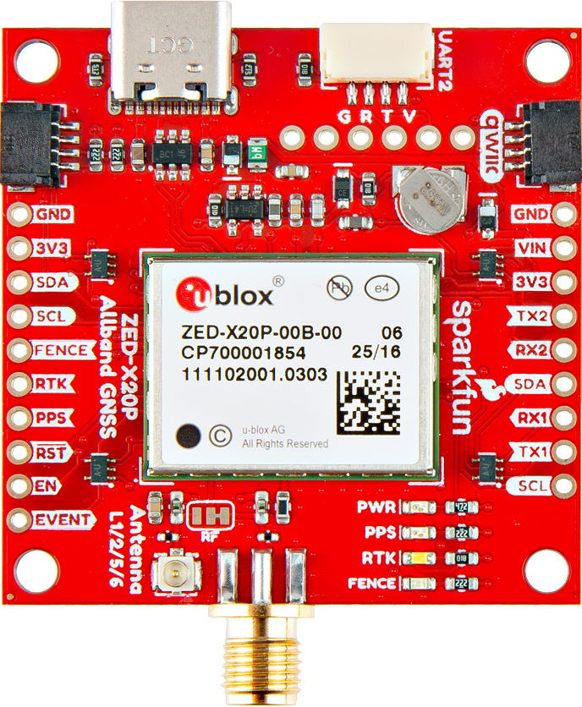
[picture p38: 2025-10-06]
docs/assets/img/hookup_guide/top.png

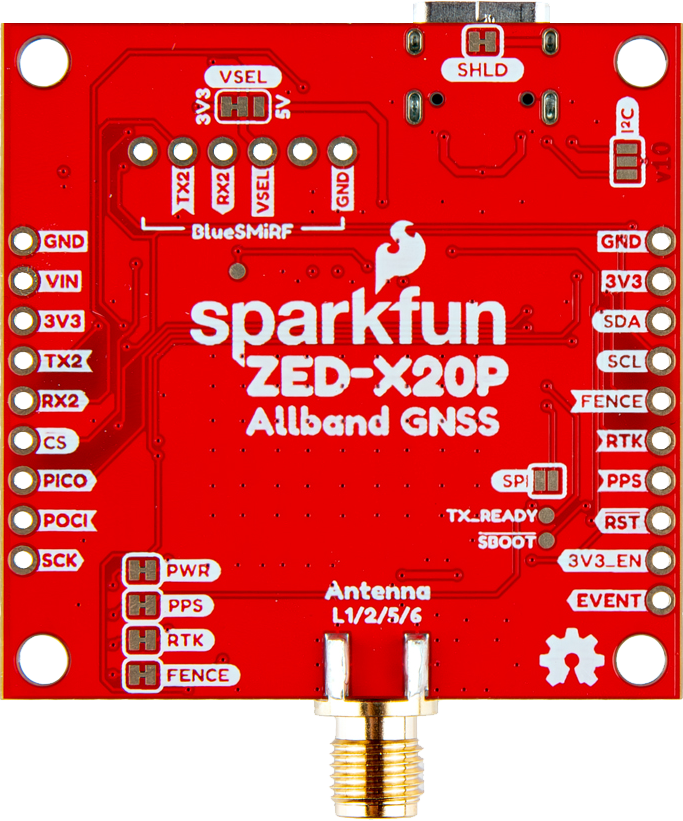
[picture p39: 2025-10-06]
docs/assets/img/hookup_guide/bottom.png

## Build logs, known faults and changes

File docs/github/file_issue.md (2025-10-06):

## Need Assistance?

<!-- Technical Assistance Box -->
!!! warning "Need Help?"
	If you need technical assistance or more information on a product that is not working as you expected, we recommend heading on over to the [SparkFun Technical Assistance](https://www.sparkfun.com/technical_assistance) page for some initial troubleshooting. This **Submit Issues** page is not where users should seek assistance.

	<article style="text-align: center;" markdown>
	[SparkFun Technical Assistance Page](https://www.sparkfun.com/technical_assistance){ .md-button .md-button--primary }
	</article>

	If you can't find what you need there, the [SparkFun Forums](https://forum.sparkfun.com) is a great place to search the product forums and ask questions.

	!!! info "Account Registration Required"
		For your first visit to our forum, you'll need to create a [Forum Account](https://community.sparkfun.com/signup) to post questions.

## Did we make a mistake?
Spot something wrong? Please let us know. 

### Discrepancies in the Documentation
All of our documentation can be modified by you! Please help us make it better.

- The documentation files for these pages are contained in the [`docs` folder](https://github.com/sparkfun/SparkFun_GNSS_ZED-X20P/tree/main/docs) of the [SparkFun GNSS ZED-X20P repository](https://github.com/sparkfun/SparkFun_GNSS_ZED-X20P).

#### 🔍 Spot something wrong?
If a section of the documentation is incorrect, please [open an issue](https://github.com/sparkfun/SparkFun_GNSS_ZED-X20P/issues) and let us know.

#### Do you have a suggested correction?

1. With a GitHub account, [fork this repository](https://github.com/sparkfun/SparkFun_GNSS_ZED-X20P/fork).
2. Add your correction(s) or improvement(s) to the markdown file(s)
3. File a pull request with your changes, and enjoy making the ~~words~~ ~~worlds~~ world a better place.
	- Once received, the documentation specialist will automatically be notified.
	- We will review your suggested improvement(s) to make sure they are correct and fit within our documentation standards.

### Problems in the Hardware Design
All of our designs are open-source! Please help us make it better.

- Our board design files are contained in the `/Hardware` directories of the [SparkFun GNSS ZED-X20P repository](https://github.com/sparkfun/SparkFun_GNSS_ZED-X20P).

#### Does something not make sense? 🤔
If part of the design is confusing, please [open an issue](https://github.com/sparkfun/SparkFun_GNSS_ZED-X20P/issues) and let us know.

#### Did we forget to include an important function of the board? 🤦
If part of the board's functionality is missing, please [open an issue](https://github.com/sparkfun/SparkFun_GNSS_ZED-X20P/issues) and file a feature request.

!!! tip "Design Considerations"
	Please keep in mind that we may intentionally exclude certain functions of the board to meet our product design requirements.

	- *For example, our Qwiic Micro boards are intended to fit on a small board layout and only use I^2^C communication; therefore, we may not have the SPI and interrupt pins available for users.*

#### Do you wish to contribute directly to improving the board design?

1. With a GitHub account, [fork this repository](https://github.com/sparkfun/SparkFun_GNSS_ZED-X20P/fork).
2. Add your design augmentation(s)
3. File a pull request with your changes, and enjoy making the ~~words~~ ~~worlds~~ world a better place.
	1. Once received, the engineer in charge of the original design will automatically be notified.
	2. We will review your suggested improvement(s) to verify that they are within our board design standards and meet our product design requirements.
	3. If approved, we will flag these changes for our next board revision. Congrats! 🍻

		!!! info
			Even if your suggestion is accepted, these changes may not be immediately available for purchase. We may have to cycle through our current product inventory first.

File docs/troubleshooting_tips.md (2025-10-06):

---
icon: sfe
---

!!! warning "Need Help?"
	If you need technical assistance or more information on a product that is not working as you expected, we recommend heading on over to the [SparkFun Technical Assistance](https://www.sparkfun.com/technical_assistance) page for some initial troubleshooting.

	<article style="text-align: center;" markdown>
	[SparkFun Technical Assistance Page](https://www.sparkfun.com/technical_assistance){ .md-button .md-button--primary }
	</article>

	If you can't find what you need there, the [SparkFun Forums](https://forum.sparkfun.com/index.php) is a great place to search product forums and ask questions.

	!!! info "Account Registration Required"
		If this is your first visit to our forum, you'll need to create a [Forum Account](https://forum.sparkfun.com/ucp.php?mode=register) to post questions.

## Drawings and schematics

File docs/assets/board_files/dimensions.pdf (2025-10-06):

43.2 | mm
8.9 | mm | 5.1 | mm ⁸.9 mm

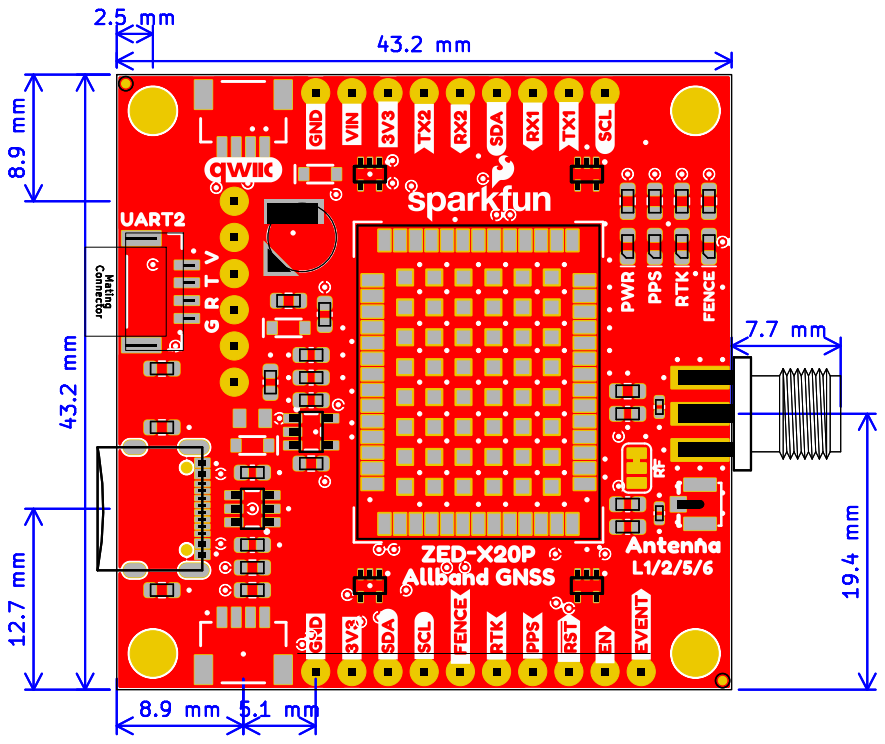
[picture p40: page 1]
19.4 mm Mating Connector Mating Connector

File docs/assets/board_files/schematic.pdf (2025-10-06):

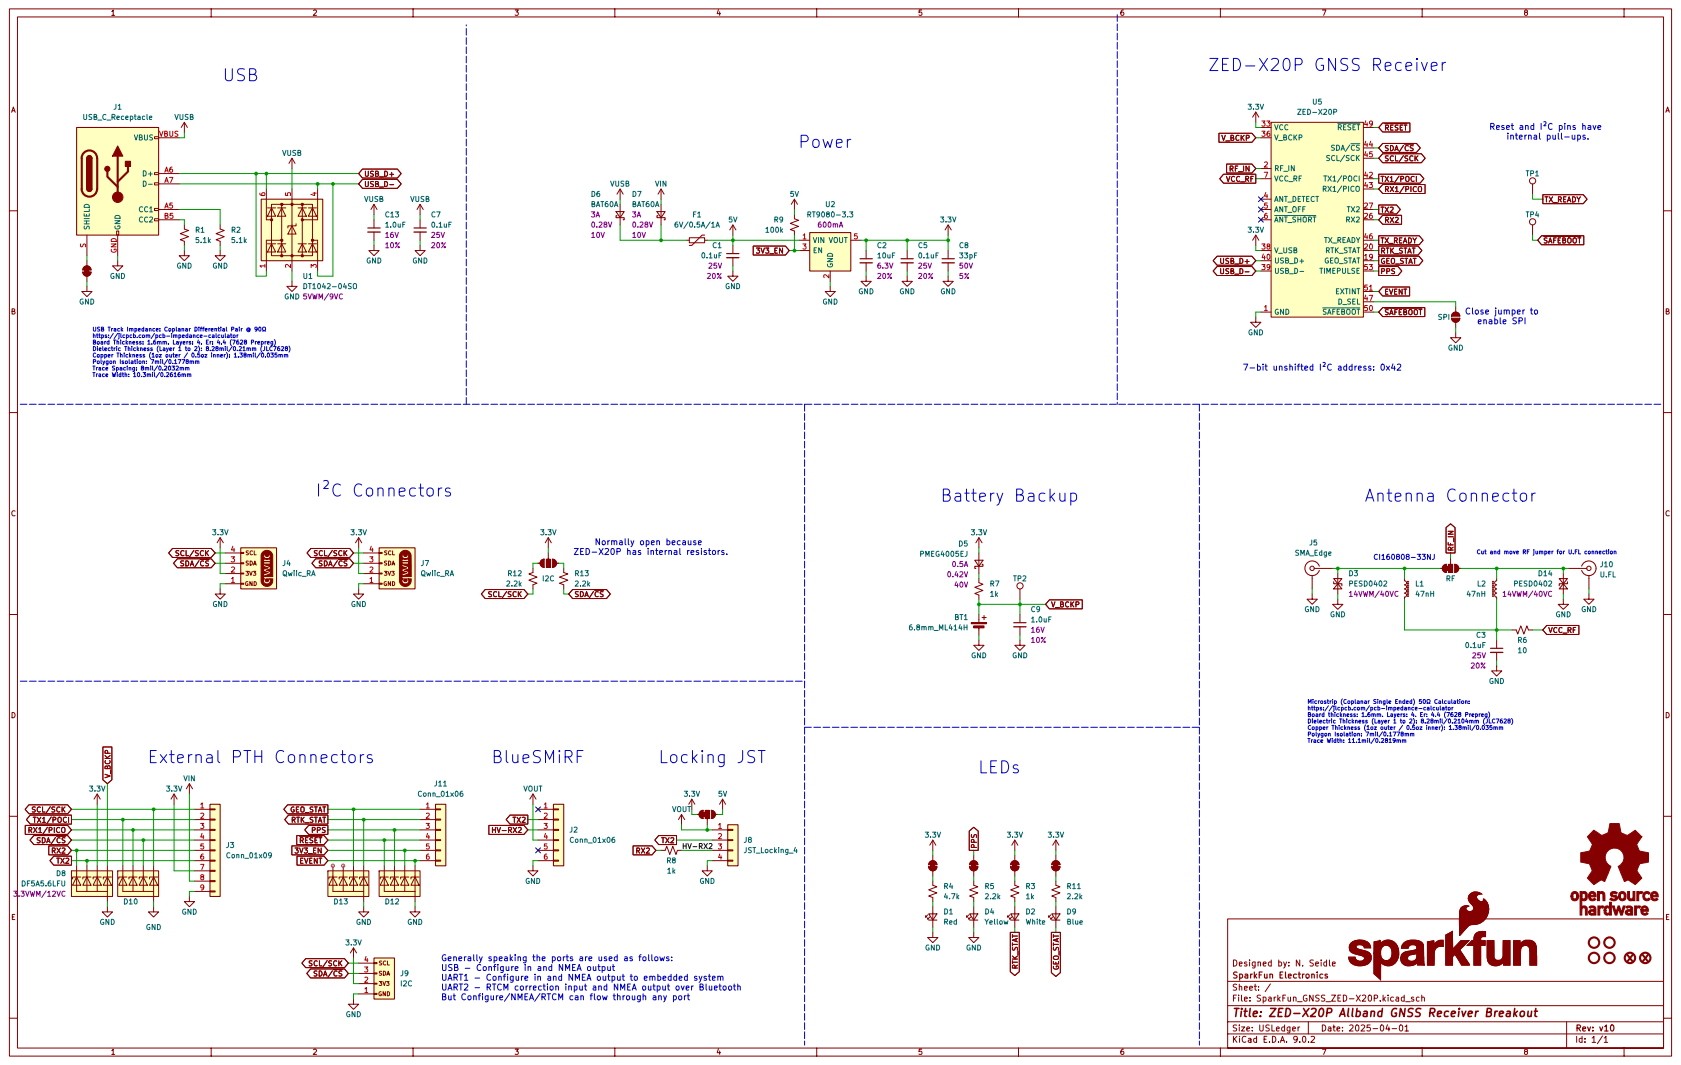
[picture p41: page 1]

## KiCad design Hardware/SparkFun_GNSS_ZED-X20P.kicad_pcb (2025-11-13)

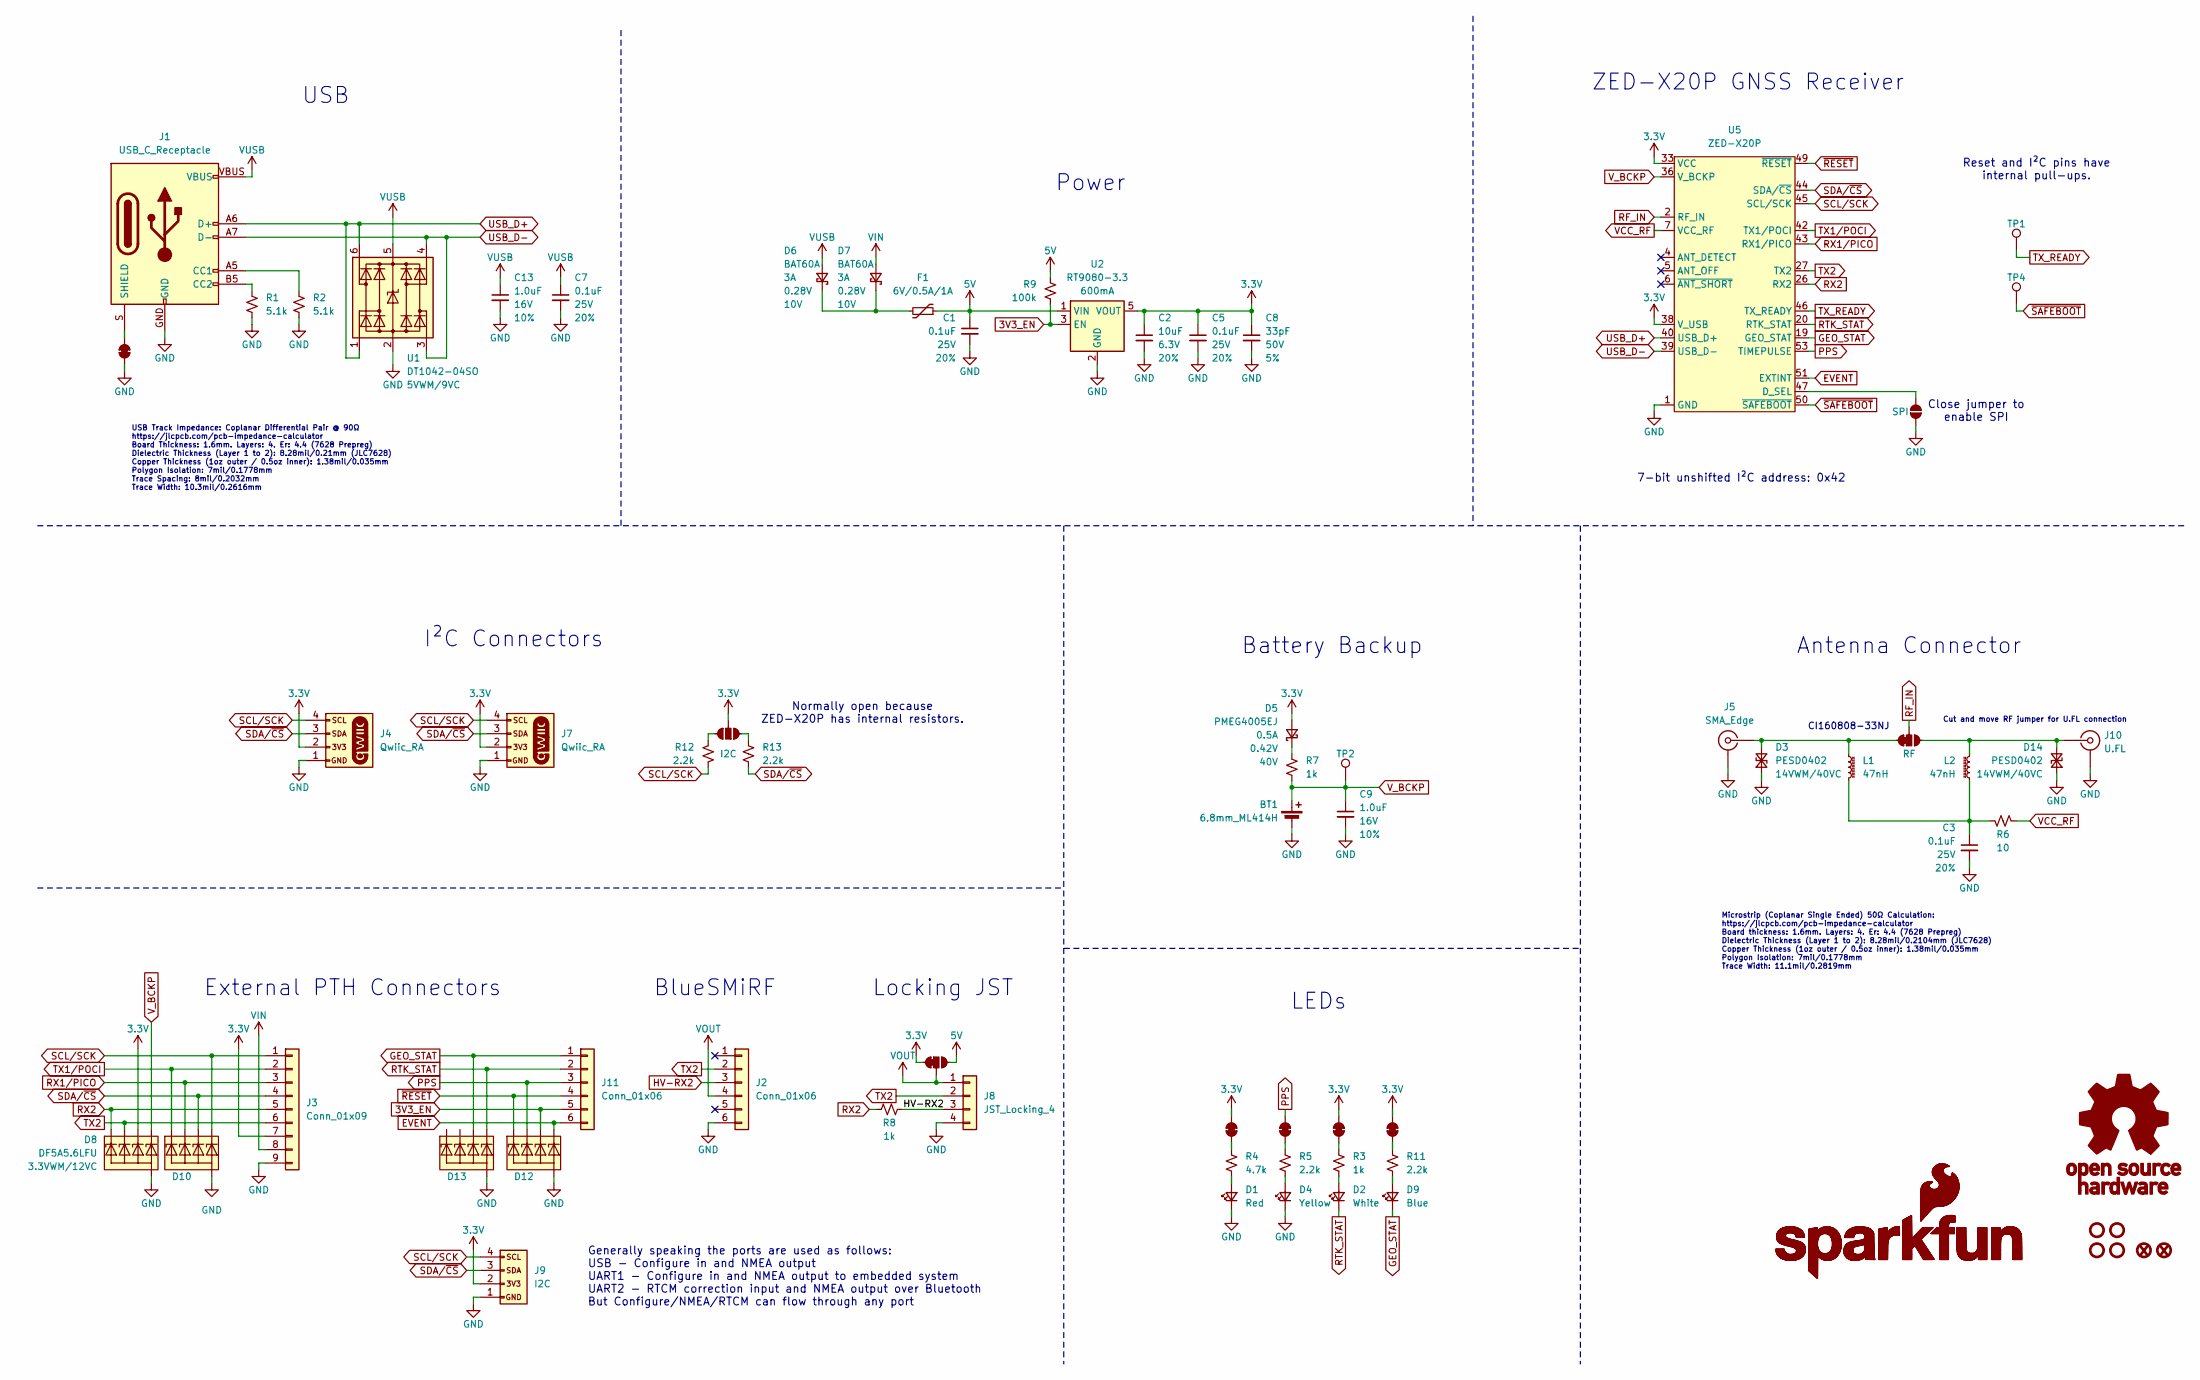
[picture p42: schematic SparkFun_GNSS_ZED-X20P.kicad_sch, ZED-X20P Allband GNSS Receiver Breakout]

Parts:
BT1: 6.8mm_ML414H; ML414H_IV01E
C1, C3, C5, C7: 0.1uF; C_0603_1608Metric; Voltage 25V; Tolerance 20%
C2: 10uF; C_0603_1608Metric; Voltage 6.3V; Tolerance 20%
C8: 33pF; C_0603_1608Metric; Voltage 50V; Tolerance 5%
C9, C13: 1.0uF; C_0603_1608Metric; Voltage 16V; Tolerance 10%
D1: Red; LED_0603_1608Metric_Red
D2: White; LED_0603_1608Metric_White
D3, D14: PESD0402; C_0402_1005Metric; Rating 14VWM/40VC
D4: Yellow; LED_0603_1608Metric_Yellow
D5: PMEG4005EJ; SOD-323
D6, D7: BAT60A; SOD-323
D8, D10, D12, D13: DF5A5.6LFU; SOT-353; Rating 3.3VWM/12VC
D9: Blue; LED_0603_1608Metric_Blue
F1: 6V/0.5A/1A; 0805
FID3, FID4: Fiducial_0.5mm; Fiducial_0.5mm_Mask1mm
G1: OSHW_Logo; Creative_Commons_License
G3: SparkFun_Logo
G5: SparkFun_Logo; SparkFun_Logo_8mm
J1: USB_C_Receptacle; USB-C_16
J2, J11: Conn_01x06; 1x06_P2.54mm
J3: Conn_01x09; 1x09_P2.54mm
J4, J7: Qwiic_RA; JST_1x04_P1.0mm_Horizontal_SMD
J5: SMA_Edge; SMA_Edge_8mm
J8: JST_Locking_4; JST_1x04_P1.25mm_Locking_Horizontal_SMD
J9: I2C; 1x04_P2.54mm
J10: U.FL
JP1: RF; Jumper_3_NC-1_Trace
JP2, JP3, JP5, JP7, JP8: Jumper_2_NC_Trace
JP4: Jumper_3_NC-1_Trace
JP9: I2C; Jumper_3_NO
JP10: SPI; Jumper_2_NO
L1, L2: 47nH; C_0603_1608Metric
R1, R2: 5.1k; R_0603_1608Metric
R3, R7, R8: 1k; R_0603_1608Metric
R4: 4.7k; R_0603_1608Metric
R5, R11, R12, R13: 2.2k; R_0603_1608Metric
R6: 10; R_0603_1608Metric
R9: 100k; R_0603_1608Metric
ST1, ST2, ST3, ST4: Standoff
TP1, TP2, TP4: 1.0mm; TestPoint-1.0mm
U1: DT1042-04SO; SOT23-6; Rating 5VWM/9VC
U2: RT9080-3.3; SOT23-5
U5: ZED-X20P; ZED-F9P_F9T_F9R_X20P

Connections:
3.3V: C2.1, C5.1, C8.1, D5.2 (A), D8.4 (K3), J3.7, J4.2, J7.2, J9.2, JP2.2 (B), JP4.1 (A), JP5.2 (B), JP8.2 (B), JP9.2 (B), U2.5 (VOUT), U5.33 (VCC), U5.34 (VCC), U5.38 (V_USB)
3V3_EN: D12.4 (K3), J11.5, R9.1, U2.3 (EN)
5V: C1.1, F1.1, JP4.3 (C), R9.2, U2.1 (VIN)
EVENT: D12.5 (K4), J11.6, U5.51 (EXTINT)
GEO_STAT: D9.1 (K), D13.4 (K3), J11.1, U5.19 (GEO_STAT)
GND: BT1.-, C1.2, C2.2, C3.2, C5.2, C7.2, C8.2, C9.2, C13.2, D1.1 (K), D3.1 (A1), D4.1 (K), D8.2 (A), D10.2 (A), D12.2 (A), D13.2 (A), D14.1 (A1), J1.GND, J2.6, J3.9, J4.1, J5.2 (Ext), J7.1, J8.4, J9.1, J10.2 (Ext), JP7.1 (A), JP10.1 (A), R1.1, R2.1, U1.2 (GND), U2.2 (GND), U5.1 (GND), U5.3 (GND), U5.12 (GND), U5.14 (GND), U5.32 (GND), U5.37 (GND), U5.41 (GND), U5.48 (GND), U5.55 (GND), U5.56 (GND), U5.57 (GND), U5.58 (GND), U5.59 (GND), U5.60 (GND), U5.61 (GND), U5.62 (GND), U5.63 (GND), U5.64 (GND), U5.65 (GND), U5.66 (GND), U5.67 (GND), U5.68 (GND), U5.69 (GND), U5.70 (GND), U5.71 (GND), U5.72 (GND), U5.73 (GND), U5.74 (GND), U5.75 (GND), U5.76 (GND), U5.77 (GND), U5.78 (GND), U5.79 (GND), U5.80 (GND), U5.81 (GND), U5.82 (GND), U5.83 (GND), U5.84 (GND), U5.85 (GND), U5.86 (GND), U5.87 (GND), U5.88 (GND), U5.89 (GND), U5.90 (GND), U5.91 (GND), U5.92 (GND), U5.93 (GND), U5.94 (GND), U5.95 (GND), U5.96 (GND), U5.97 (GND), U5.98 (GND), U5.99 (GND), U5.100 (GND), U5.101 (GND), U5.102 (GND)
HV-RX2: J2.3, J8.3, R8.1
unnamed: C3.1, L1.2, L2.2, R6.2
unnamed: D1.2 (A), R4.1
unnamed: D2.2 (A), R3.1
unnamed: D3.2 (A2), J5.1 (In), JP1.1 (A), L1.1
unnamed: D4.2 (A), R5.1
unnamed: D5.1 (K), R7.2
unnamed: D6.1 (K), D7.1 (K), F1.2
unnamed: D9.2 (A), R11.1
unnamed: D14.2 (A2), J10.1 (In), JP1.3 (C), L2.1
unnamed: J1.A5 (CC1), R2.2
unnamed: J1.B5 (CC2), R1.2
unnamed: J1.S (SHIELD), JP7.2 (B)
unnamed: JP2.1 (A), R4.2
unnamed: JP3.1 (A), R5.2
unnamed: JP5.1 (A), R3.2
unnamed: JP8.1 (A), R11.2
unnamed: JP9.1 (A), R13.1
unnamed: JP9.3 (C), R12.1
unnamed: JP10.2 (B), U5.47 (D_SEL)
PPS: D12.3 (K2), J11.3, JP3.2 (B), U5.53 (TIMEPULSE)
RF_IN: JP1.2 (B), U5.2 (RF_IN)
RTK_STAT: D2.1 (K), D13.5 (K4), J11.2, U5.20 (RTK_STAT)
RX1/PICO: D10.3 (K2), J3.3, U5.43 (RX1/PICO)
RX2: D8.1 (K1), J3.5, R8.2, U5.26 (RX2)
SCL/SCK: D10.5 (K4), J3.1, J4.4, J7.4, J9.4, R12.2, U5.45 (SCL/SCK)
SDA/~CS: D10.4 (K3), J3.4, J4.3, J7.3, J9.3, R13.2, U5.44 (SDA/~CS)
TX1/POCI: D10.1 (K1), J3.2, U5.42 (TX1/POCI)
TX2: D8.3 (K2), J2.2, J3.6, J8.2, U5.27 (TX2)
TX_READY: TP1.1, U5.46 (TX_READY)
USB_D+: J1.A6 (D+), J1.B6 (D+), U1.1 (I/O1), U1.6 (I/O4), U5.40 (USB_D+)
USB_D-: J1.A7 (D-), J1.B7 (D-), U1.3 (I/O2), U1.4 (I/O3), U5.39 (USB_D-)
VCC_RF: R6.1, U5.7 (VCC_RF)
VIN: D7.2 (A), J3.8
VOUT: J2.4, J8.1, JP4.2 (B)
VUSB: C7.1, C13.1, D6.2 (A), J1.VBUS, U1.5 (VCC)
V_BCKP: BT1.+, C9.1, D8.5 (K4), R7.1, TP2.1, U5.36 (V_BCKP)
~RESET: D12.1 (K1), J11.4, U5.49 (~RESET)
~SAFEBOOT: TP4.1, U5.50 (~SAFEBOOT)

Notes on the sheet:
7-bit unshifted I²C address: 0x42
CI160808-33NJ
I²C Connectors
Microstrip (Coplanar Single Ended) 50Ω Calculation: https://jlcpcb.com/pcb-impedance-calculator Board thickness: 1.6mm. Layers: 4. Er: 4.4 (7628 Prepreg) Dielectric Thickness (Layer 1 to 2): 8.28mil/0.2104mm (JLC7628) Copper Thickness (1oz outer / 0.5oz inner): 1.38mil/0.035mm Polygon Isolation: 7m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
Generally speaking the ports are used as follows: USB - Configure in and NMEA output UART1 - Configure in and NMEA output to embedded system UART2 - RTCM correction input and NMEA output over Bluetooth But Configure/NMEA/RTCM can flow through any port
USB Track Impedance: Coplanar Differential Pair @ 90Ω https://jlcpcb.com/pcb-impedance-calculator Board Thickness: 1.6mm. Layers: 4. Er: 4.4 (7628 Prepreg) Dielectric Thickness (Layer 1 to 2): 8.28mil/0.21mm (JLC7628) Copper Thickness (1oz outer / 0.5oz inner): 1.38mil/0.035mm Polygon Isolation: 7m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
Cut and move RF jumper for U.FL connection
BlueSMiRF
Reset and I²C pins have internal pull-ups.
Locking JST
Power
Antenna Connector
LEDs
ZED-X20P GNSS Receiver
Close jumper to enable SPI
USB
Battery Backup
External PTH Connectors
Normally open because ZED-X20P has internal resistors.

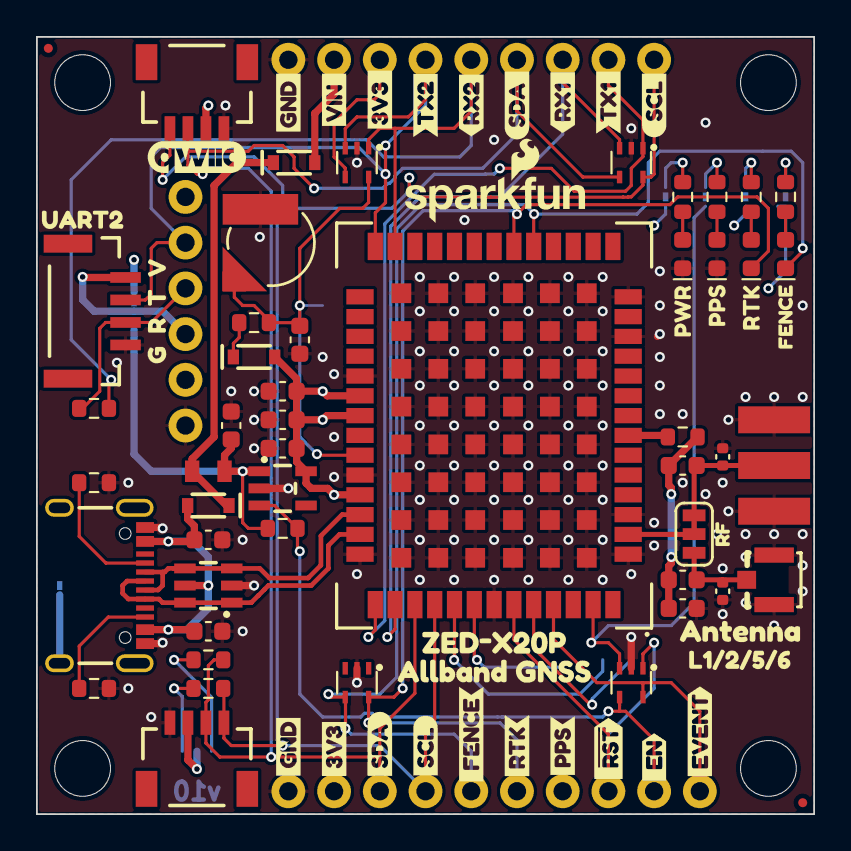
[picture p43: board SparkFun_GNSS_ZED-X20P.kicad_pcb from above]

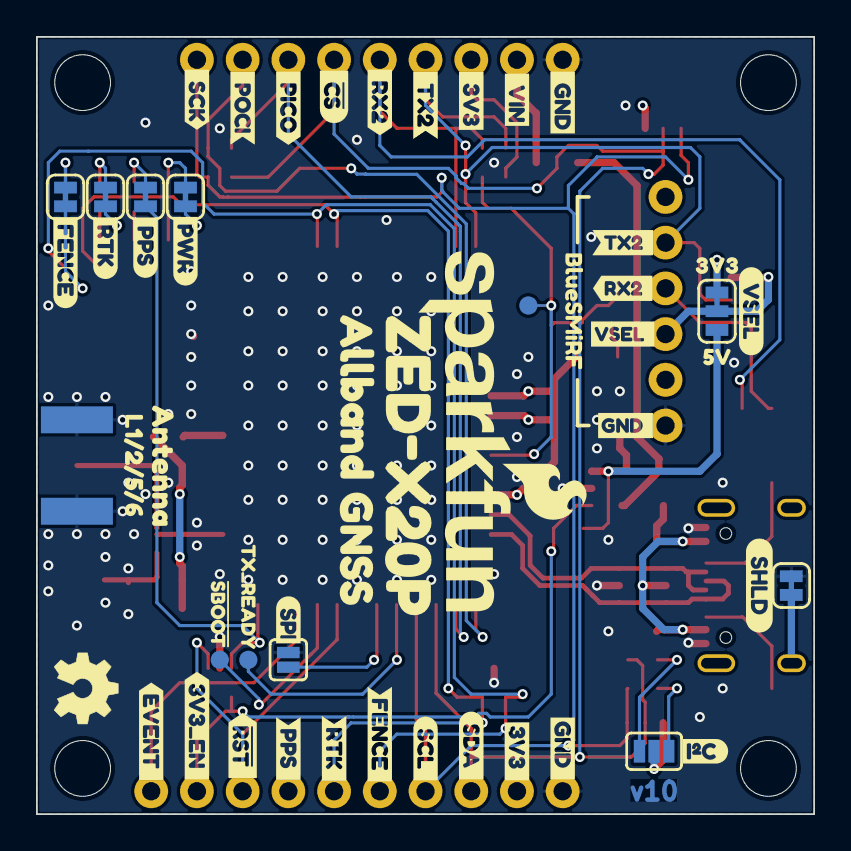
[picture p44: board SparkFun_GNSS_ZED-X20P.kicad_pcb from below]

Board: 4 copper layers, 43.2 x 43.2 mm, 140 parts (52 on the bottom side), 45 nets.

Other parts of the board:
Ref**: Val**; OSHW_Logo_4mm
kibuzzard-64C2E6A3: G***; kibuzzard-64C2E6A3
kibuzzard-64C2E6BD: G***; kibuzzard-64C2E6BD
kibuzzard-64C2E6D6: G***; kibuzzard-64C2E6D6
kibuzzard-64C3DF93: G***; kibuzzard-64C3DF93
kibuzzard-66CAA7B2: G***; kibuzzard-66CAA7B2
kibuzzard-66CAA41A: G***; kibuzzard-66CAA41A
kibuzzard-66CAA426: G***; kibuzzard-66CAA426
kibuzzard-66CAA432: G***; kibuzzard-66CAA432
kibuzzard-66CAA594: G***; kibuzzard-66CAA594
kibuzzard-66CB82FB: G***; kibuzzard-66CB82FB
kibuzzard-66CB829C: G***; kibuzzard-66CB829C
kibuzzard-66CB830B: G***; kibuzzard-66CB830B
kibuzzard-67EC5C53: G***; kibuzzard-67EC5C53
kibuzzard-67EC52D7: G***; kibuzzard-67EC52D7
kibuzzard-67EC52E7: G***; kibuzzard-67EC52E7
kibuzzard-67EC55E2: G***; kibuzzard-67EC55E2
kibuzzard-67EC56CE, kibuzzard-67EC56CE#2: G***; kibuzzard-67EC56CE
kibuzzard-67EC56E0, kibuzzard-67EC56E0#2: G***; kibuzzard-67EC56E0
kibuzzard-67EC56FC: G***; kibuzzard-67EC56FC
kibuzzard-67EC530B: G***; kibuzzard-67EC530B
kibuzzard-67EC532A: G***; kibuzzard-67EC532A
kibuzzard-67EC572D: G***; kibuzzard-67EC572D
kibuzzard-67EC5004: G***; kibuzzard-67EC5004
kibuzzard-67EC5083: G***; kibuzzard-67EC5083
kibuzzard-67EC5549: G***; kibuzzard-67EC5549
kibuzzard-67EC5701: G***; kibuzzard-67EC5701
kibuzzard-67EC5939: G***; kibuzzard-67EC5939
kibuzzard-67ED9A4D: G***; kibuzzard-67ED9A4D
kibuzzard-67ED9A5A: G***; kibuzzard-67ED9A5A
kibuzzard-67ED9A5D: G***; kibuzzard-67ED9A5D
kibuzzard-67ED9A28: G***; kibuzzard-67ED9A28
kibuzzard-67ED9A70: G***; kibuzzard-67ED9A70
kibuzzard-67ED9C3D: G***; kibuzzard-67ED9C3D
kibuzzard-67ED9D32: G***; kibuzzard-67ED9D32
kibuzzard-67ED9ED8: G***; kibuzzard-67ED9ED8
kibuzzard-67ED93D1: G***; kibuzzard-67ED93D1
kibuzzard-680A971A: G***; kibuzzard-680A971A
kibuzzard-680A972D: G***; kibuzzard-680A972D
kibuzzard-680A9713: G***; kibuzzard-680A9713
kibuzzard-680A9725: G***; kibuzzard-680A9725
kibuzzard-6501FDDA: G***; kibuzzard-6501FDDA
kibuzzard-6797CE3B: G***; kibuzzard-6797CE3B
kibuzzard-6797CE4B: G***; kibuzzard-6797CE4B
kibuzzard-6797CE48: G***; kibuzzard-6797CE48
kibuzzard-6797CF40: G***; kibuzzard-6797CF40
kibuzzard-6797CFD5: G***; kibuzzard-6797CFD5
kibuzzard-6797CFD9: G***; kibuzzard-6797CFD9
kibuzzard-6797CFEB: G***; kibuzzard-6797CFEB
kibuzzard-6797D0AD: G***; kibuzzard-6797D0AD
kibuzzard-6797D0B5: G***; kibuzzard-6797D0B5
kibuzzard-6797D0B9: G***; kibuzzard-6797D0B9
kibuzzard-6797D0BE: G***; kibuzzard-6797D0BE
kibuzzard-6797D1E0: G***; kibuzzard-6797D1E0
kibuzzard-6797D04A: G***; kibuzzard-6797D04A
kibuzzard-6797D04F: G***; kibuzzard-6797D04F
kibuzzard-6797D06C: G***; kibuzzard-6797D06C
kibuzzard-6797D07B: G***; kibuzzard-6797D07B
kibuzzard-6797D08B: G***; kibuzzard-6797D08B
kibuzzard-6797D08F: G***; kibuzzard-6797D08F
kibuzzard-6797D21D: G***; kibuzzard-6797D21D
kibuzzard-6797D058: G***; kibuzzard-6797D058
kibuzzard-6797D071: G***; kibuzzard-6797D071
kibuzzard-6797D081: G***; kibuzzard-6797D081
kibuzzard-6797D086: G***; kibuzzard-6797D086
kibuzzard-6797D093: G***; kibuzzard-6797D093
kibuzzard-6797D096: G***; kibuzzard-6797D096
kibuzzard-6797D214: G***; kibuzzard-6797D214
kibuzzard-6797D229: G***; kibuzzard-6797D229

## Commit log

2025-04-02 Post airwire review
    [SparkFun_GNSS_ZED-X20P.kicad_pcb, SparkFun_GNSS_ZED-X20P.kicad_sch]
2025-04-03 Update to v9.
    [SparkFun_GNSS_ZED-X20P.kicad_pcb, SparkFun_GNSS_ZED-X20P.kicad_sch]
2025-04-24 Add panel
    [SparkFun_GNSS_ZED-X20P.kicad_pcb, SparkFun_GNSS_ZED-X20P.kicad_sch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]
2025-10-06 Initial Docs Commit
    [SparkFun_GNSS_ZED-X20P.kicad_pcb, cad_model.step]
2025-11-13 Update to new symbol/fp locations
    [SparkFun_GNSS_ZED-X20P.kicad_pcb, SparkFun_GNSS_ZED-X20P.kicad_sch]
2026-09-18 Update hardware_overview.md
    Fix grammar
    Updat UART messages
    Add firmware version
    Add bug - board redesign

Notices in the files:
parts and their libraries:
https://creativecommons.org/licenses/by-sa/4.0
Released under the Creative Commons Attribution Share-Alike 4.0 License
